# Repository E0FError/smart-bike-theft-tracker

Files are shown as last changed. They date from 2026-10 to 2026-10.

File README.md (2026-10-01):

# Smart Bike Theft Tracker — GPS + LoRaWAN, Ultra-Low Power







A complete, analysis-driven hardware design for an **anti-bike-theft tracker**:
an ultra-low-power device that sleeps until an accelerometer detects movement,
then acquires its position with GPS and transmits an alert with coordinates over
**LoRaWAN**. The design covers everything the brief demanded — a deep-sleep MCU,
a full battery/charger/regulator power tree, motion sensing, GPS, RF layout and
a quantified **power budget**.

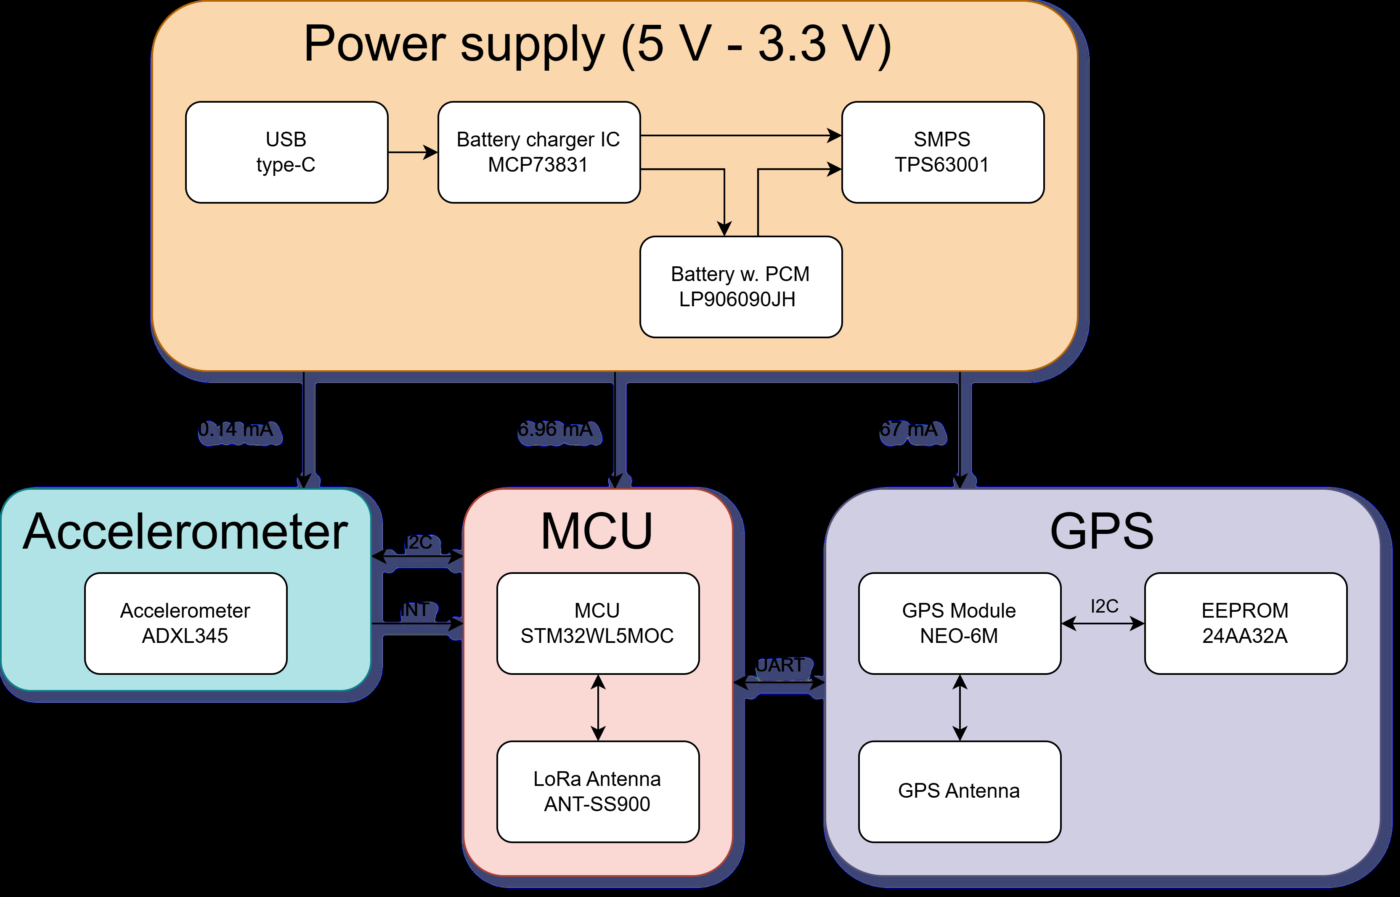
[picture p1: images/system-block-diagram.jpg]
System block diagram


> **Group 11 — co-designed.** This was the two-person final project for the DTU
> course *34374 IoT Hardware and PCB Design*, built with
> **Louis Sønderby Pelletier**. The report is included in
> [`docs/`](docs/Group11_Final_Project_Report.pdf).

---

## What I worked on

The project was a full two-person collaboration. From the report's group
contribution table, my (**Finn Oskar Grabbe**) primary ownership was:

| Area | My contribution |
|---|---|
| Accelerometer | Component choice + `GyroSense` schematic + layout |
| GPS | Component choice + `GPS` schematic + layout |
| PCB layout | Board layout (placement, routing, RF feeds) |

Louis led the introduction/architecture, the MCU and power-supply component
choices, the power design and the power budget, plus the power/MCU schematics
and layout. Everything was reviewed together.

---

## Design at a glance

| Parameter | Value |
|---|---|
| Application | Bike theft tracker: motion → GPS fix → LoRaWAN alert |
| MCU + radio | **STM32WL5MOCH6TR** (Cortex-M4 + M0+, integrated LoRaWAN, no external crystals/matching) |
| Motion sensor | **ADXL345BCCZ-RL7** 3-axis accelerometer, interrupt to MCU `WKUP1` |
| GPS | **u-blox NEO-6M-0-001** (UART NMEA) + U.FL antenna + backup cell |
| LoRa antenna | SMA edge launch (`SMA-J-P-H-ST-EM1`) for an `ANT-SS900` |
| Arming | 2-position slide switch (`500SSP1S1M2QEA`) on an MCU GPIO |
| Charger | **MCP73831T-2ACI/OT** from USB-C |
| Battery | **Jauch LP605060JU**, 1900 mAh LiPo with protection (PCM) |
| Regulator | **TPS63001** buck-boost → 3.3 V (chosen over an LDO) |
| Peak current | ≈ 74 mA (MCU 7 mA + accelerometer 0.14 mA + GPS 67 mA) |
| Battery life | **≈ 5.4 days** worst case; ≈ weekly charging in practice |
| PCB | 4-layer FR-4, ≈ 57 × 41 mm, 50 Ω controlled-impedance RF |

---

## 1. System architecture

Four functional blocks map directly onto the hierarchical schematic:

| Sheet | Block | Key parts |
|---|---|---|
| `Top.SchDoc` | Hierarchy | `U_GPS`, `U_GyroSense`, `U_MCU`, `U_BatteryCharger` |
| `BatteryCharger.SchDoc` | Power | MCP73831 charger, TPS63001 buck-boost, USB-C, JST, slide switch |
| `MCU.SchDoc` | Compute + radio | STM32WL5MOCH6TR, LoRa SMA, decoupling |
| `GyroSense.SchDoc` | Motion | ADXL345, I²C pull-up, decoupling |
| `GPS.SchDoc` | Positioning | NEO-6M, U.FL antenna, backup cell, load-switch gating |

### Operation

1. **Sleep** — ARMED, no movement. MCU standby ≈ 125 nA; GPS in power-save with
   the backup domain alive; accelerometer at a low ODR.
2. **Wake** — the ADXL345 pulls its interrupt to the MCU. The MCU checks the
   slide switch: DISARMED → back to standby, ARMED → continue.
3. **GPS fix** — the GPS rail is enabled and NMEA is read over UART. The backup
   cell makes this a **hot start**.
4. **LoRa TX** — coordinates are transmitted as a LoRaWAN alert; the system
   returns to sleep.

---

## 2. Component choices

### MCU + LoRaWAN — STM32WL5MOCH6TR
The decisive advantage is the **integrated LoRaWAN radio with in-package
matching network and oscillators** — no external RF matching, no crystals —
which shrinks the board and removes the most error-prone RF layout work. It
provides I²C/SPI/UART/ADC, interrupt wake pins and a very low standby current.
It costs more (≈ €12.43) than a €5–10 STM32, but the savings in board area,
design risk and complexity justify it, and STM's documentation is excellent.

### Motion — ADXL345BCCZ-RL7
A 3-axis, 3 × 5 mm accelerometer with built-in **activity/inactivity, tap and
free-fall** detection and a FIFO. Its interrupt output drives the MCU wake pin
(`WKUP1`/`PA0`), so the system never has to poll — this is what makes the
sub-milliamp sleep budget achievable.

### GPS — u-blox NEO-6M-0-001
A self-contained receiver with a **simple UART interface** (9600 bps NMEA),
16 × 12.2 × 2.4 mm and 2.7–3.6 V. It offloads all navigation processing from
the host. The trade-off, called out in the report, is that the NEO-6 family is
**End-of-Life** — acceptable for this design because a current u-blox module is a
drop-in pin-compatible upgrade. A **backup coin cell** (`STPS0540Z` + retainer)
enables a fast hot start at the moment of theft.

### Power — MCP73831 charger, Jauch protected LiPo, TPS63001 regulator
- **MCP73831T-2ACI/OT**: single-cell 4.2 V Li-Ion/LiPo charger with a status
  output, from a USB-C receptacle (`USB4125-GF-A-0190`) with 5.1 kΩ CC pulldowns.
- **Jauch LP605060JU**, 1900 mAh, with an integrated **protection circuit
  module** — the design's stated battery-protection assumption and a size match
  for the board.
- **TPS63001 buck-boost** for 3.3 V — see below.

Full parts list: [`docs/bom.md`](docs/bom.md) ·
[`hardware/Group11_BOM.csv`](hardware/Group11_BOM.csv).

---

## 3. Power design — why a buck-boost, not an LDO

The brief required an explicit LDO-vs-SMPS comparison. An **MCP1700 LDO** was
evaluated against the **TPS63001 buck-boost** at the 74 mA peak load:

| | MCP1700 (LDO) | TPS63001 (buck-boost) |
|---|---|---|
| Minimum input | 3.3 V·1.03 + 0.35 V = **3.749 V** | **1.8 V** |
| Loss at 74 mA | 33.2 mW | 27.1 mW (η ≈ 90 %) |
| Quiescent current | **4 µA** | 51.5 µA |
| Complexity | 2 capacitors | inductor + more passives |

The LDO has the better quiescent current and simplicity, **but its minimum input
of 3.75 V is higher than the usable voltage of a LiPo cell** (down to ~3.0 V),
so it cannot hold regulation across a full discharge. The buck-boost keeps
3.3 V from 1.8 V up, and is slightly more efficient. It was therefore selected:

$$
I_{in}=\frac{3.3\,\text{V}\times74\,\text{mA}}{0.8\times3.0\,\text{V}}=101.8\,\text{mA}
\quad\text{(well under the cell's 380 mA, 0.2 C rating)}
$$

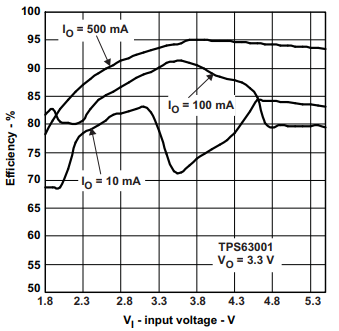
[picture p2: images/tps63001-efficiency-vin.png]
TPS63001 efficiency vs input voltage


---

## 4. Power budget & battery life

Three operating states were modelled, each component's draw taken from its
datasheet and referred to the battery through the SMPS efficiency:

| Component | Sleep | GPS fix | LoRa TX |
|---|---:|---:|---:|
| MCU | 125 nA | 1.1 mA | 1.1 mA |
| GPS | 11 mA | 47 mA | 11 mA |
| Backup battery | 879 µA | 0 mA | 0 mA |
| Accelerometer | 30 µA | 30 µA | 30 µA |
| SMPS output | 12 mA | 48 mA | 12 mA |
| **Battery discharge** | **14.7 mA** | **51.8 mA** | **14.7 mA** |

With one 1-minute hot-start fix per day:

$$
14.7\,\text{mA}\times24\,\text{h}+51.8\,\text{mA}\times\tfrac{1}{60}\,\text{h}
=353.7\ \tfrac{\text{mAh}}{\text{day}}
\;\Rightarrow\;
\text{Battery life}=\frac{1900}{353.7}=5.4\ \text{days}
$$

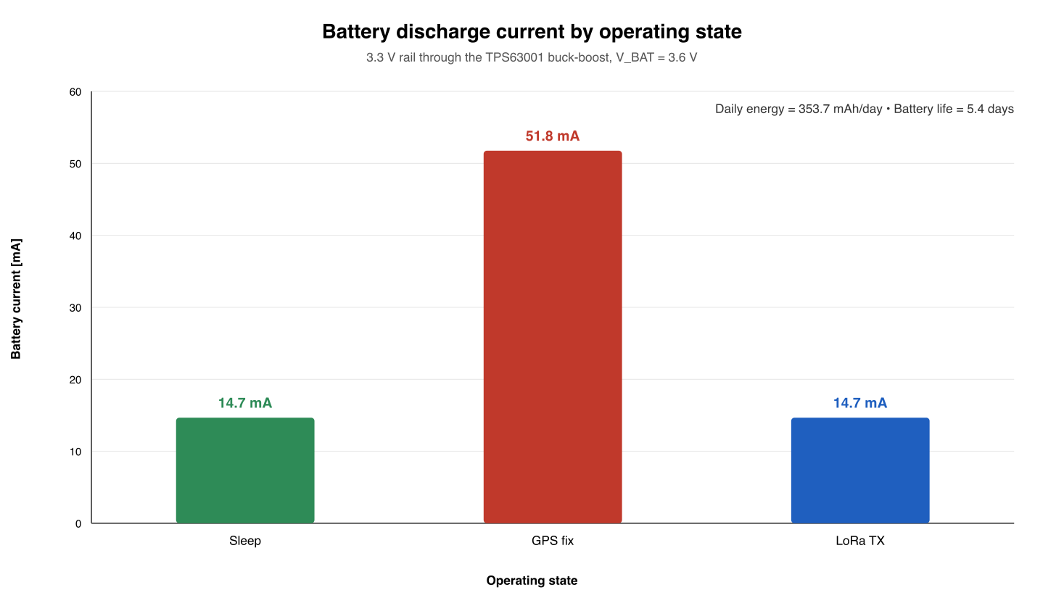
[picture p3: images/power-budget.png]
Battery discharge current by state


This 5.4 days is the **worst case** (full-use); the tracker transmits only on an
actual alert, so it needs charging roughly **once a week**.

---

## 5. RF & PCB layout

The board is a **4-layer FR-4** design (≈ 57 × 41 mm). Both antenna feeds are
**50 Ω controlled-impedance coplanar waveguides with ground**, with via stitching
to confine the field and stabilise impedance.

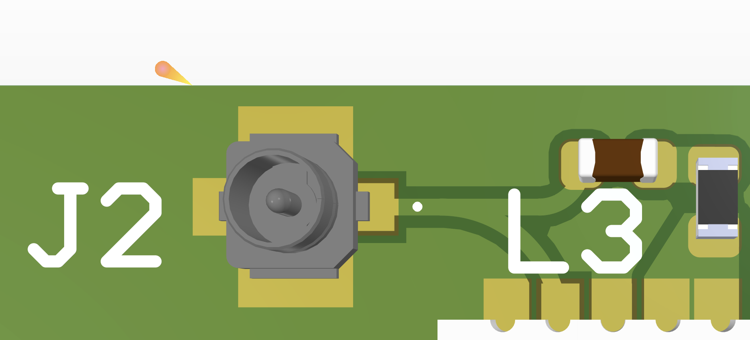
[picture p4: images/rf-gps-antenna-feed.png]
GPS antenna feed

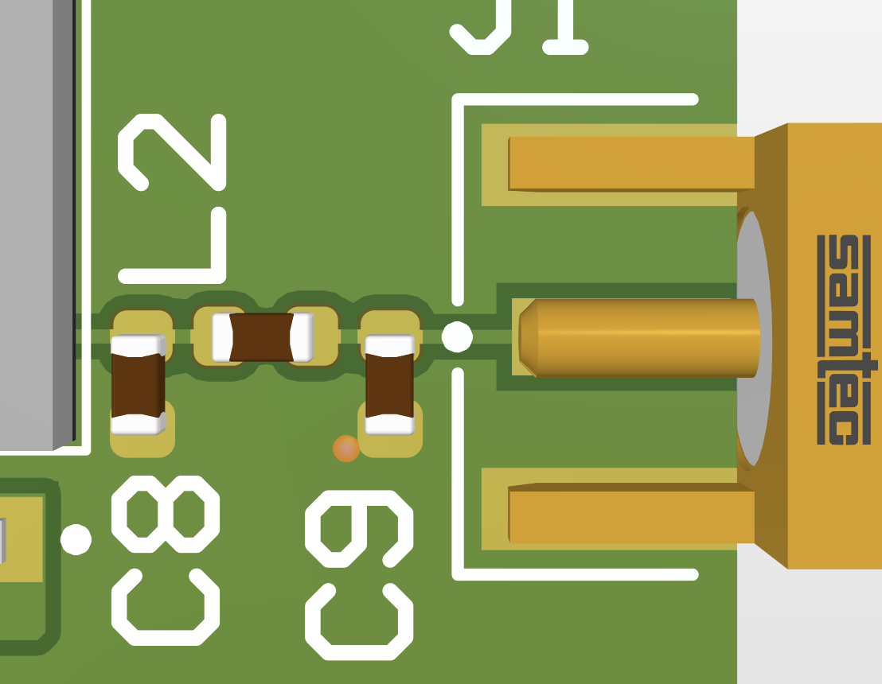
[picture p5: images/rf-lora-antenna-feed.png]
LoRa antenna feed


RF best practices applied:

- **LoRa** — straight feed to the edge-mounted SMA at 868/915 MHz.
- **GPS** — short **curved** feed to the U.FL connector at 1575.42 MHz; arcs
  avoid the impedance perturbation of 90° corners.
- **Continuous reference plane** beneath the RF traces (no splits).
- **Direct ground connections** on RF pads — thermal spokes add inductance.
- **No layer transitions** on the feeds — vias add parasitic inductance and
  reflections.

The 3.3 V rail is routed **star-style** from the regulator instead of
daisy-chaining loads, so transient currents do not create local supply dips:

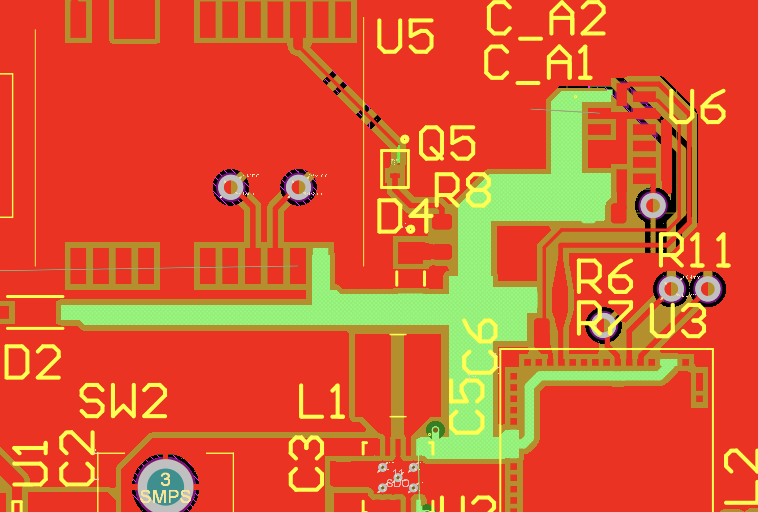
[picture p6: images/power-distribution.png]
3.3 V power distribution


---

## 6. Schematic & PCB

The design is captured as a **four-sheet hierarchical schematic** plus a
**4-layer PCB**. The full schematic PDF is in
[`hardware/Smart_Bike_Theft_Tracker_Schematics.pdf`](hardware/Smart_Bike_Theft_Tracker_Schematics.pdf).

**Top hierarchy** — the four functional blocks and the harness ports between
them:

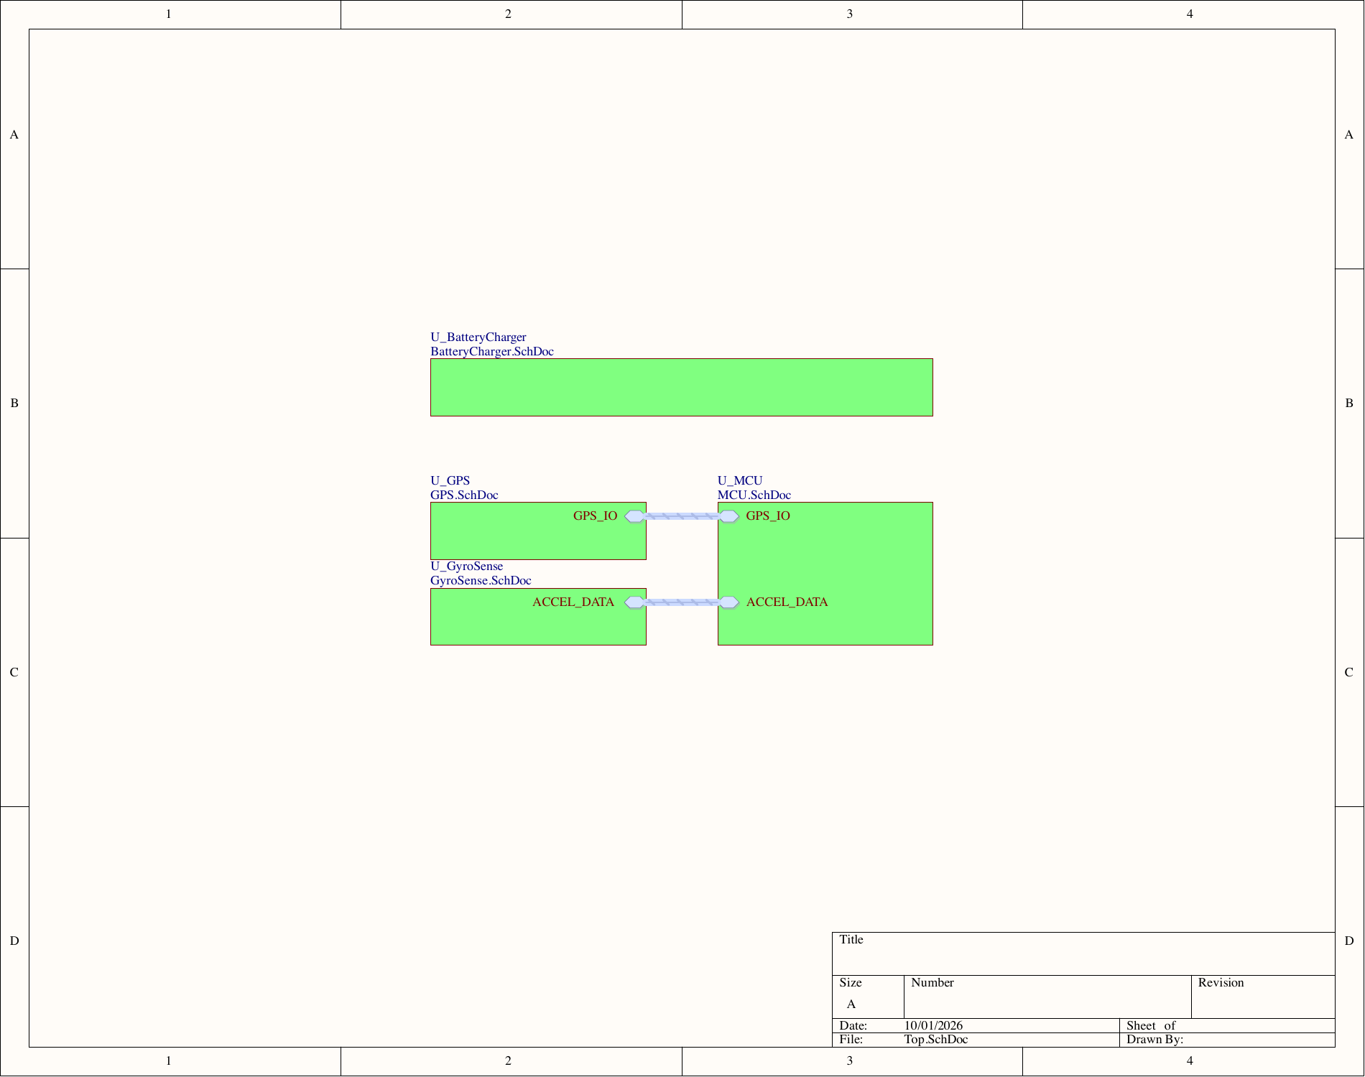
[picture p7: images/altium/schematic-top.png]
Top hierarchy sheet


| Power — charger + buck-boost | MCU + LoRaWAN |
|---|---|
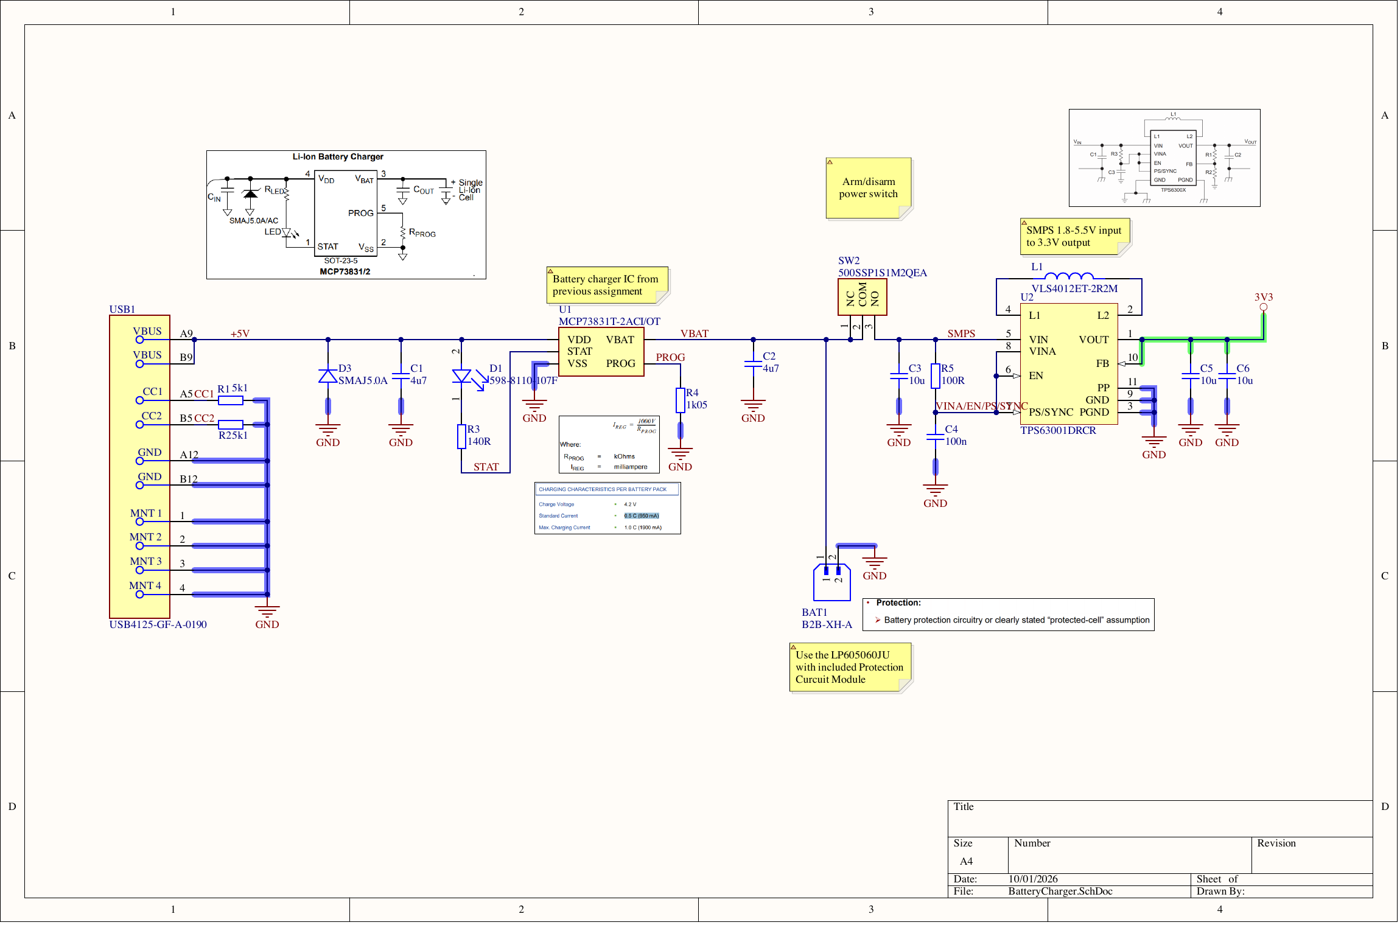
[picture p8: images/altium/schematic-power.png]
Power schematic
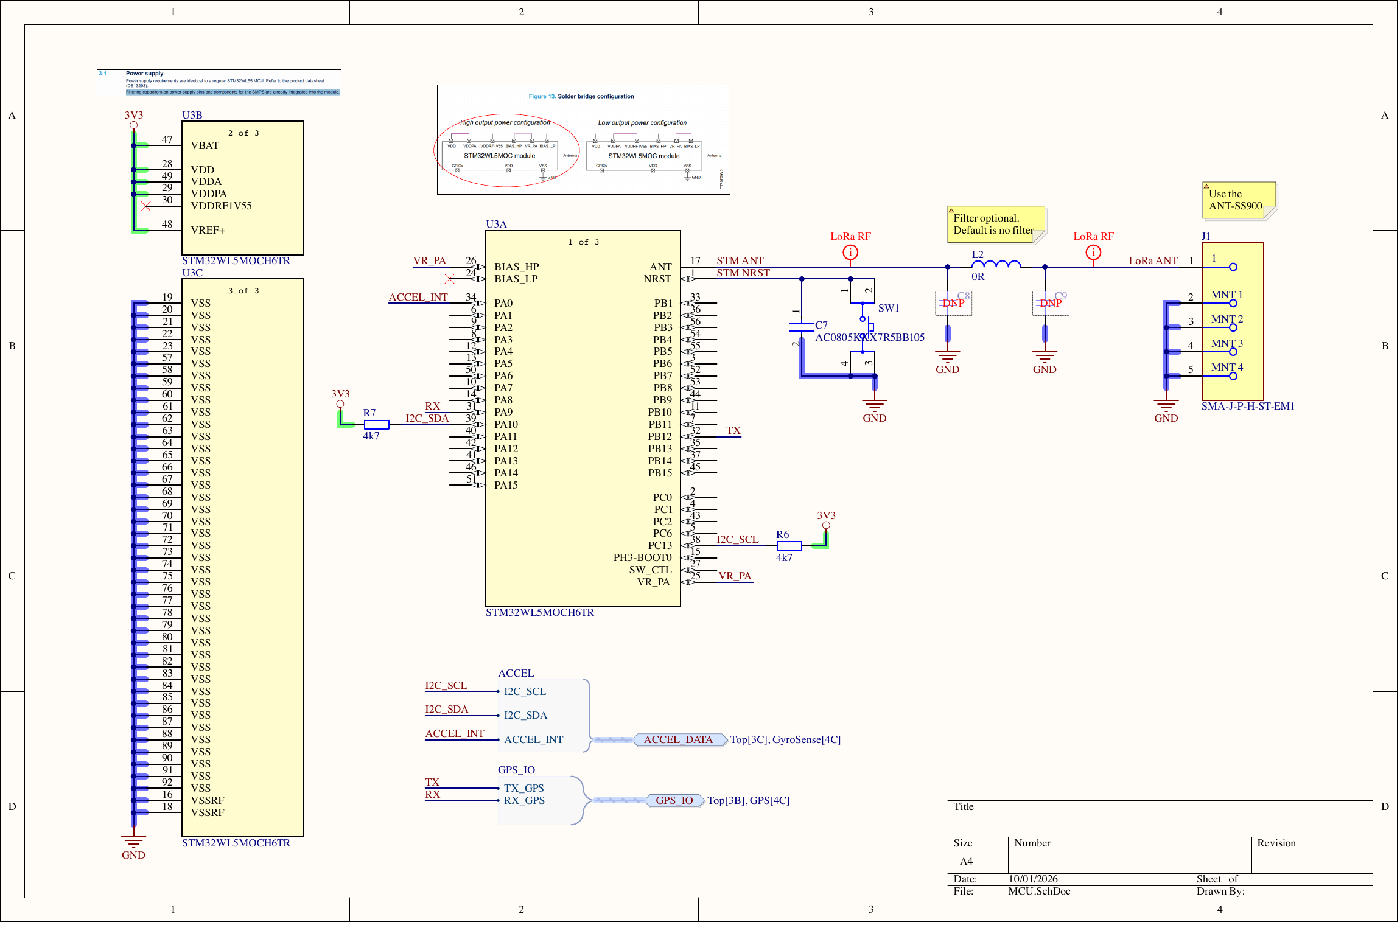
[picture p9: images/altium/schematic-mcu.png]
MCU schematic
|  |  |
| **Accelerometer (GyroSense)** | **GPS** |
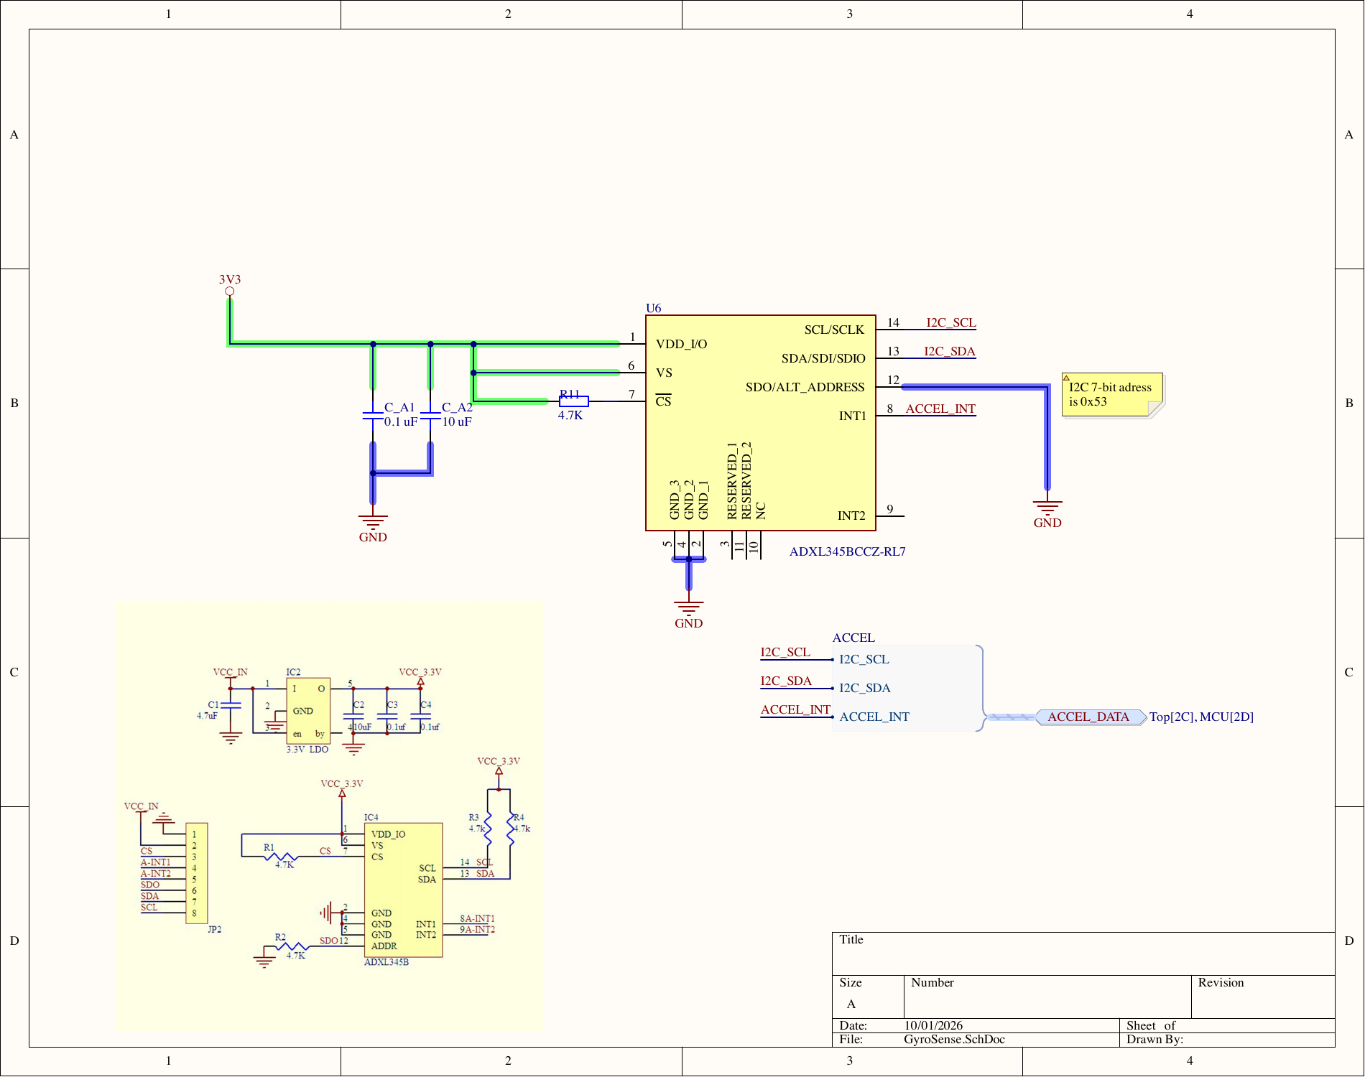
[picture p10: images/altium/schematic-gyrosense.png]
Accelerometer schematic
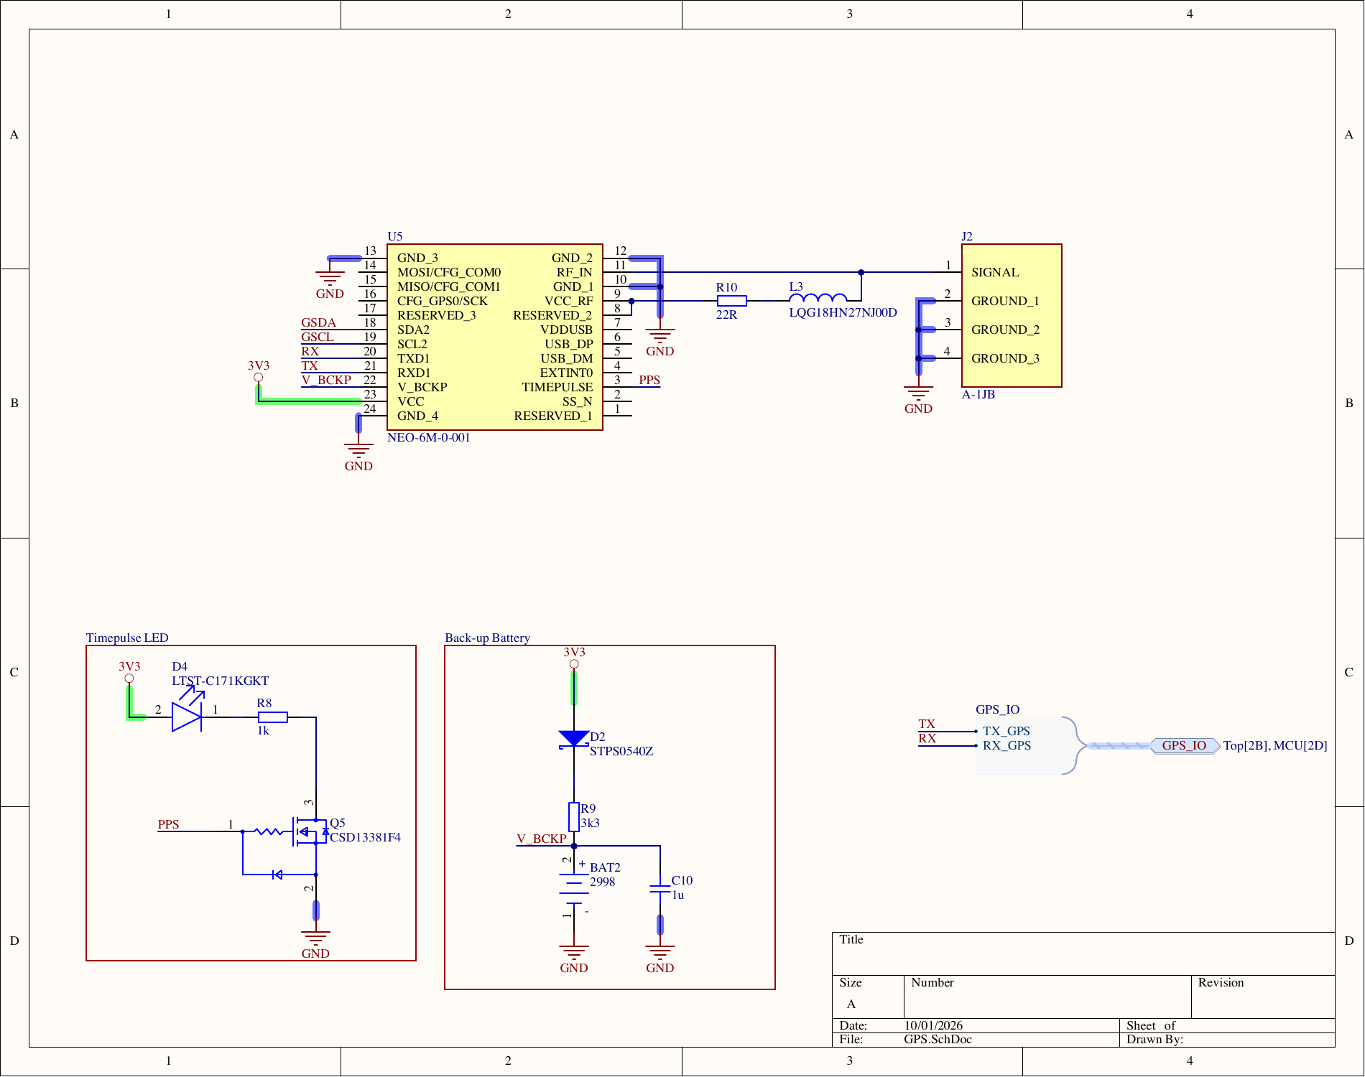
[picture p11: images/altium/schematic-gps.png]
GPS schematic
|  |  |

### PCB layout

The top-copper view shows the RF feeds, the star-distributed 3.3 V rail and the
connector placement (USB-C, JST, SMA, U.FL):

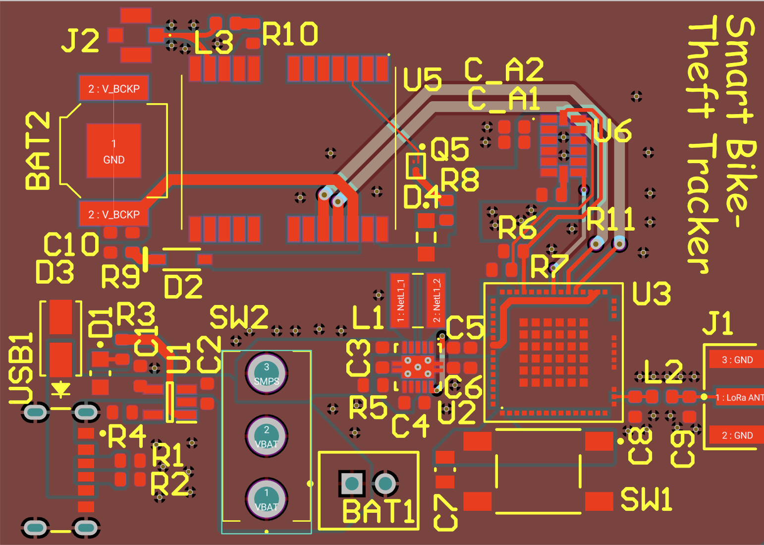
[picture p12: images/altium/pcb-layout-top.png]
PCB top layer


### 3D model

An isometric view of the assembled board. The native 3D model is included in
[`hardware/Smart_Bike_Theft_Tracker.step`](hardware/Smart_Bike_Theft_Tracker.step).

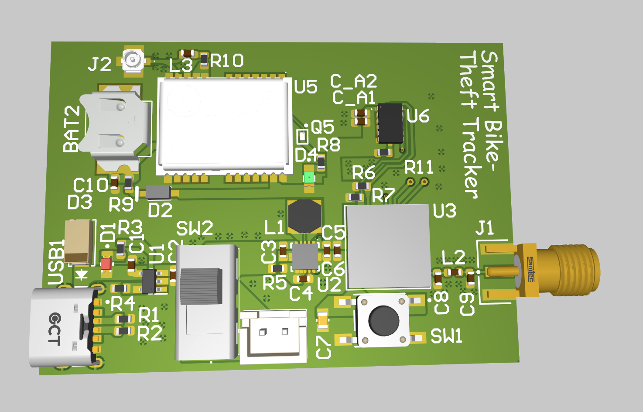
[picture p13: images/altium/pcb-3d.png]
3D render of the tracker PCB


---

## 7. Repository contents

```
smart-bike-theft-tracker/
├── README.md
├── hardware/                              # Altium project (+ generated BOM)
│   ├── Smart Bike Theft Tracker (...).PrjPcb
│   ├── Top.SchDoc  BatteryCharger.SchDoc  MCU.SchDoc
│   ├── GyroSense.SchDoc  GPS.SchDoc  *.Harness
│   ├── Smart Bike Theft Tracker.PcbDoc    # 4-layer PCB
│   ├── Schlib1.SchLib  PcbLib1.PcbLib
│   ├── Smart_Bike_Theft_Tracker_Schematics.pdf   # all sheets
│   ├── Smart_Bike_Theft_Tracker.step              # 3D model
│   └── Group11_BOM.csv
├── docs/
│   ├── Group11_Final_Project_Report.pdf   # the submitted report
│   ├── system-design.md                   # architecture + design rationale
│   └── bom.md
├── analysis/
│   ├── power_budget.py                    # states, LDO/SMPS, battery life
│   ├── extract_bom.py                     # SchDoc -> BOM CSV
│   └── power_budget.json
├── tools/
│   └── render_schdoc.py                   # Altium SchDoc -> SVG renderer
└── images/
    ├── system-block-diagram.jpg  power-budget.png
    ├── rf-gps-antenna-feed.png   rf-lora-antenna-feed.png
    ├── power-distribution.png
    └── altium/                            # exported schematic + PCB images
```

## 8. Reproducing the analysis

No third-party packages are required:

```bash
python3 analysis/power_budget.py      # power budget, LDO/SMPS, battery life + figure
python3 analysis/extract_bom.py       # regenerate hardware/Group11_BOM.csv
python3 tools/render_schdoc.py hardware/MCU.SchDoc mcu.svg --title "MCU"
```

To inspect the hardware, open the `.PrjPcb` in **Altium Designer**.

## 9. References

- STMicroelectronics — STM32WL5M dual-core LoRaWAN module.
- Analog Devices — ADXL345 3-axis digital accelerometer.
- u-blox — NEO-6M GPS receiver.
- Microchip — MCP73831 charger; Texas Instruments — TPS63001 buck-boost.
- Course material: *34374 IoT Hardware and PCB Design*, Final Project brief, DTU.

---

### Attribution & academic use

DTU 34374 final project, Group 11 — Finn Oskar Grabbe & Louis Sønderby
Pelletier. Shared publicly for portfolio purposes. If you are taking the course,
please use it for reference only and produce your own work.

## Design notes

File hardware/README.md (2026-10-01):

# Hardware sources (Altium Designer)

Altium Designer project for the **Smart Bike Theft Tracker**
(GPS + LoRaWAN, ultra-low power), Group 11.

| File | Contents |
|---|---|
| `Smart Bike Theft Tracker (GPS + LoRaWAN, Ultra-Low Power).PrjPcb` | Altium project — **open this file** |
| `Top.SchDoc` | Top-level hierarchy |
| `BatteryCharger.SchDoc` | USB-C, MCP73831 charger, TPS63001 buck-boost |
| `MCU.SchDoc` | STM32WL5MOCH6TR + LoRa antenna |
| `GyroSense.SchDoc` | ADXL345 accelerometer |
| `GPS.SchDoc` | NEO-6M GPS + antenna + power gating |
| `*.Harness` | Harness definitions for the sheet ports |
| `Smart Bike Theft Tracker.PcbDoc` | 4-layer PCB layout |
| `Schlib1.SchLib` / `PcbLib1.PcbLib` | Symbols and footprints |
| `Smart_Bike_Theft_Tracker_Schematics.pdf` | All schematic sheets, exported from Altium |
| `Smart_Bike_Theft_Tracker.step` | 3D STEP model of the assembled board |
| `Group11_BOM.csv` | BOM exported by `../analysis/extract_bom.py` |

## Opening the project

1. Open **Altium Designer**.
2. `File → Open` and select the `.PrjPcb` file above.
3. The four hierarchical sheets and the PCB load automatically.

## Notes

- The board is a **4-layer** stack; the RF feeds are 50 Ω controlled-impedance
  coplanar waveguides with ground (see the design notes).
- Altium artefacts (`__Previews/`, `History/`, `Project Logs*/`,
  `Project Outputs*/`) are excluded by `.gitignore` and regenerate on open.
- High-resolution schematic and PCB images exported from Altium live in
  [`../images/altium/`](../images/altium/).

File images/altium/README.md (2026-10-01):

# Image exports

Board images from the Altium project for the **Smart Bike Theft Tracker**
(DTU 34374 final project, Group 11).

| File | View |
|---|---|
| `schematic-top.png` | Top-level hierarchy — four sheet symbols and the harness ports between them |
| `schematic-power.png` | `BatteryCharger.SchDoc` — USB-C, MCP73831 charger, TPS63001 buck-boost |
| `schematic-mcu.png` | `MCU.SchDoc` — STM32WL5MOCH6TR and the LoRa SMA feed |
| `schematic-gyrosense.png` | `GyroSense.SchDoc` — ADXL345 accelerometer |
| `schematic-gps.png` | `GPS.SchDoc` — NEO-6M, U.FL antenna and backup cell |
| `pcb-layout-top.png` | PCB top-copper layer — RF feeds, 3.3 V rail and connector placement |
| `pcb-3d.png` | Isometric 3D view of the assembled board |

The native design files — schematics, PCB, symbol/footprint libraries, the
schematic PDF and the STEP 3D model — are in
[`../../hardware/`](../../hardware/).

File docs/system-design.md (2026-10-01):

# System design — Smart Bike Theft Tracker

Design rationale for the GPS + LoRaWAN ultra-low-power bike theft tracker.
Numbers match the design report and the scripts in `analysis/`.

---

## 1. Requirements

| # | Requirement | Implementation |
|---|---|---|
| 1 | Motion detection that can wake the MCU from deep sleep | **ADXL345** activity interrupt → MCU `WKUP1`/`PA0` |
| 2 | ARMED / DISARMED user control | 2-position **slide switch** on an MCU GPIO |
| 3 | Acquire position | **u-blox NEO-6M** GPS over UART + antenna |
| 4 | Transmit alert + coordinates | **STM32WL5M** integrated LoRaWAN + SMA antenna |
| 5 | Battery-powered with charger and regulation | USB-C → **MCP73831** → 1900 mAh LiPo → **TPS63001** 3.3 V |
| 6 | 50 Ω controlled-impedance RF feeds and antenna placement | Coplanar waveguide with ground on a 4-layer stack |

The brief is **design & analysis only** — no fabrication, purchasing or assembly.

---

## 2. System architecture

System block diagram

The device is organised into four functional blocks that mirror the schematic
hierarchy:

| Sheet | Block | Key parts |
|---|---|---|
| `Top.SchDoc` | Hierarchy | sheet symbols `U_GPS`, `U_GyroSense`, `U_MCU`, `U_BatteryCharger` |
| `BatteryCharger.SchDoc` | Power | MCP73831 charger, TPS63001 buck-boost, USB-C, JST, slide switch |
| `MCU.SchDoc` | Compute + radio | STM32WL5MOCH6TR, LoRa SMA connector, decoupling |
| `GyroSense.SchDoc` | Motion | ADXL345, I²C pull-up, decoupling |
| `GPS.SchDoc` | Positioning | NEO-6M, U.FL antenna, backup cell, power gating |

Data flows: the accelerometer raises an interrupt, the MCU reads it over I²C,
checks the slide-switch state, powers up the GPS, reads NMEA over UART and then
transmits the fix over the integrated LoRaWAN radio.

### Firmware / operation flow

1. **SLEEP** — ARMED, no movement. MCU in standby (`125 nA`), GPS in power-save
   with its backup domain alive, accelerometer at a low ODR only for interrupts.
2. **Motion interrupt** — the ADXL345 pulls the wake pin; the MCU wakes and
   checks the slide switch. If DISARMED it ignores the event and returns to
   standby.
3. **GPS FIX** — the MCU enables the GPS rail (via the load MOSFET) and reads
   NMEA over UART. A hot start is assumed because the backup cell keeps the
   ephemeris.
4. **LoRa TX** — the coordinates are sent as a LoRaWAN alert; the system then
   returns to sleep.

---

## 3. Component choices

### MCU + LoRaWAN — STM32WL5MOCH6TR
- Dual-core Cortex-M4 (application) + Cortex-M0+ (radio), with the **SX126x
  LoRa radio integrated in-package**.
- Integrated oscillator network and antenna matching/PA network — **no external
  crystals or discrete matching** required, which shrinks the PCB and removes RF
  layout risk.
- I²C, SPI, UART, ADC and interrupt-capable wake pins, with a very low standby
  current. The trade-off is cost (≈ €12.43 vs €5–10 for similar STM32s), which is
  outweighed by reduced complexity, size and STM's documentation/support.

### Accelerometer — ADXL345BCCZ-RL7
- 3-axis, I²C/SPI, 3 mm × 5 mm package, FIFO and built-in **activity / tap /
  inactivity / free-fall** detection.
- Its interrupt output connects to `WKUP1` (`PA0`) so the sensor can wake the
  system directly from deep sleep — no polling, which is what makes the
  low-power budget possible.

### GPS — u-blox NEO-6M-0-001
- Self-contained receiver with a **simple UART** interface (default 9600 bps
  NMEA), 16 mm × 12.2 mm × 2.4 mm, 2.7–3.6 V.
- Drawback: the NEO-6 family is **End-of-Life**; acceptable here because the
  module removes navigation processing from the host and is easy to power-gate.
- A **backup coin cell** (retainer + Schottky `STPS0540Z`) keeps the RTC and
  ephemeris alive so the theft fix can be a **hot start**.

### Charger — MCP73831T-2ACI/OT + Jauch LP605060JU
- 4.2 V single-cell Li-Ion/LiPo charger, programmable current, status output.
- Battery: **Jauch LP605060JU, 1900 mAh**, with an integrated **protection
  circuit module (PCM)** — this is the stated battery-protection assumption.
- USB-C input (`USB4125-GF-A-0190`) with 5.1 kΩ CC pull-downs.

### Regulator — TPS63001 (chosen over an LDO)
See §4.

---

## 4. Power design: LDO vs buck-boost

An **MCP1700 LDO** was compared against the **TPS63001 buck-boost** for the
3.3 V rail at the 74 mA peak load.

| Criterion | MCP1700 (LDO) | TPS63001 (buck-boost) |
|---|---|---|
| Minimum input | 3.3 V·1.03 + 0.35 V = **3.749 V** | **1.8 V** |
| Loss at peak load | 33.2 mW | 27.1 mW (η ≈ 90 %) |
| Quiescent current | **4 µA** | 51.5 µA |
| Complexity | 2 capacitors | inductor + more passives |

The LDO wins on quiescent current and simplicity, but its **minimum input of
3.75 V is above the usable voltage of a LiPo cell** (which falls to ~3.0 V). It
therefore cannot regulate across the whole discharge curve, while the
buck-boost both keeps 3.3 V down to 1.8 V in and is slightly more efficient.
The **TPS63001** was selected on that basis:

$$
P_{out}=3.3\,\text{V}\times74\,\text{mA}=244.2\,\text{mW},\qquad
I_{in}=\frac{244.2\,\text{mW}}{0.8\times3.0\,\text{V}}=101.8\,\text{mA}
$$

which is well within the cell's 0.2 C (≈380 mA) discharge rating.

TPS63001 efficiency vs input voltage

---

## 5. Power budget & battery life

Three states are defined; each component's current draw comes from its
datasheet, and the SMPS efficiency converts the 3.3 V load into battery current:

$$
I_{bat}=\frac{V_{rail}\cdot I_{out}}{\eta\cdot V_{bat}}
$$

| Component | Sleep | GPS fix | LoRa TX |
|---|---:|---:|---:|
| MCU | 125 nA | 1.1 mA | 1.1 mA |
| GPS | 11 mA | 47 mA | 11 mA |
| Backup battery | 879 µA | 0 mA | 0 mA |
| Accelerometer | 30 µA | 30 µA | 30 µA |
| **SMPS output** | 12 mA | 48 mA | 12 mA |
| **Battery discharge** | **14.7 mA** | **51.8 mA** | **14.7 mA** |

Daily energy (one 1-minute hot-start fix per day):

$$
14.7\,\text{mA}\times24\,\text{h}+51.8\,\text{mA}\times\tfrac{1}{60}\,\text{h}
=353.7\ \tfrac{\text{mAh}}{\text{day}}
$$

$$
\text{Battery life}=\frac{1900\,\text{mAh}}{353.7\,\text{mAh/day}}
=5.4\ \text{days (worst case)}
$$

Battery discharge current by state

In practice the GPS only needs a fix at an alert, so the tracker only needs
charging about **once a week**.

---

## 6. RF & PCB layout

The board is a **4-layer FR-4** stack. Both antenna feeds are **50 Ω
controlled-impedance coplanar waveguides with ground**, with **via stitching**
to confine the field and stabilise the impedance.

GPS antenna feed
LoRa antenna feed

RF rules applied:

- **LoRa:** straight feed to the edge-mounted SMA (`SMA-J-P-H-ST-EM1`) for the
  `ANT-SS900` antenna, at 868/915 MHz.
- **GPS:** short, **curved** trace to the `A-1JB` U.FL connector at 1575.42 MHz;
  arcs are preferred over 90° corners to avoid impedance perturbations.
- **Continuous reference plane** under every RF trace — no splits, since a
  discontinuity in the return path degrades the effective impedance.
- **Direct ground connections** (no thermal spokes) on RF ground pads, because
  spokes add inductance at RF.
- **No layer transitions** on the feeds — vias would add parasitic inductance
  and reflections.

### Power distribution

The 3.3 V rail is distributed **star-style** directly from the buck-boost
rather than daisy-chained, so transient current from one block does not create
a supply dip at another:

3.3 V power distribution

---

## 7. Assumptions & limitations

- Analysis only: no board was fabricated, so all currents/efficiency figures
  are datasheet- or simulation-based.
- GPS fix time assumed to be **1 minute** (datasheet hot start ≈ 15 s) as a
  conservative margin.
- SMPS efficiencies assumed 75 % (light load) / 85–90 % (heavy load) from the
  datasheet curves.
- The `NEO-6M` is End-of-Life; a production revision would move to a current
  u-blox module.
- Battery protection is credited to the cell's integrated PCM.
- The slide switch is a proof of concept for ARM/DISARM; the report notes NFC
  as a more realistic product-grade alternative.

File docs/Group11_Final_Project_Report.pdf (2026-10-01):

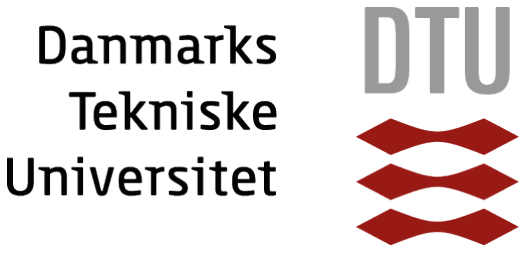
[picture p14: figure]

# Smart Bike Theft Tracker

Authors

Finn Oskar Grabbe - s252818 Louis Sønderby Pelletier - s254381

May 29, 2026

Smart Bike Theft Tracker | Contents

# Contents

1 Introduction & Requirements | 2
2 System Architecture | 3
3 Component Choices | 4
4 Power Design | 6
5 RF & PCB Layout | 8
6 Power Budget & Battery Life | 10
Chapter/HW block | Author
Intro | Louis
Architecture | Louis
Comp. MCU | Louis
Comp. AMU | Finn
Comp. GPS | Finn
Comp. Power supply | Louis
Power design | Louis
PCB Layout | Finn
Power budget | Louis
Power supply schem. & layout | Louis
MCU schem. & layout | Louis
AMU schem. & layout | Finn
GPS schem. & layout | Finn

Smart Bike Theft Tracker

# 1 Introduction & Requirements

The goal of this project is to design the hardware aspect of an anti bike theft device, that has the capability to detect motion, pinpoint bike location using GPS and transmitting an alert and bike coordinates via LoRa to the bike owner in case of theft. The device must also include a way to arm and disarm the device (e.g. a switch) to avoid false theft detection, and the device must also include an ultra low power mode to limit current draw while it is stationary or in the unarmed state.
We will implement motion detection using an accelerometer, that has the capability of producing an interrupt when movement is detected. This will be used to wake the MCU up from the deep sleep state in case the bike is armed and is stolen.
To arm and disarm the device, we will use a slide switch as a proof of concept. In practice a slide switch is too simple and obvious for a device of this nature, but implementing a different arming solution is not complicated (NFC would be a good alternative for a device like this). While the device is armed, the interrupt from the accelerometer will tell the MCU that the device is being stolen, and while the device is unarmed the MCU will stay in sleep mode.
A GPS will track the position of the device, and in case of a theft the MCU will get the current coordinates from here. The GPS will require an antenna to establish a connection to satellites. In case of a theft, the owner of the bike will receive an alert on their mobile device through LoRa along with the current coordinates of the bike.

Smart Bike Theft Tracker

# 2 System Architecture

A block diagram of the Smart Bike Theft tracker can be seen in figure 2.1. It shows each major block of the system with key components under each block. The peak current draw of key blocks is also included to provide an overview of total current draw and the balance of power draw of each major block.
The power supply block is powered through a USB type-C terminal to comply with EU legislation. A battery charger IC uses the 5 V from the USB to charge the battery and to drive the Switch Mode Power Supply, which powers the rest of the system with 3.3 V.
The accelerometer draws 140 µA of current at peak and will send an interrupt to the MCU block when movement is detected. The MCU can communicate with the accelerometer through I2C. The MCU draws about 7 mA at peak current draw. This includes the draw of the LoRa module as it is included in the MCU chip.
The GPS block will have the largest current draw at peak, but the 67 mA is a worst case scenario over several GPS modules in NEO-6 family. It will likely be lower in practice. In total the peak current draw will be about 74 mA.

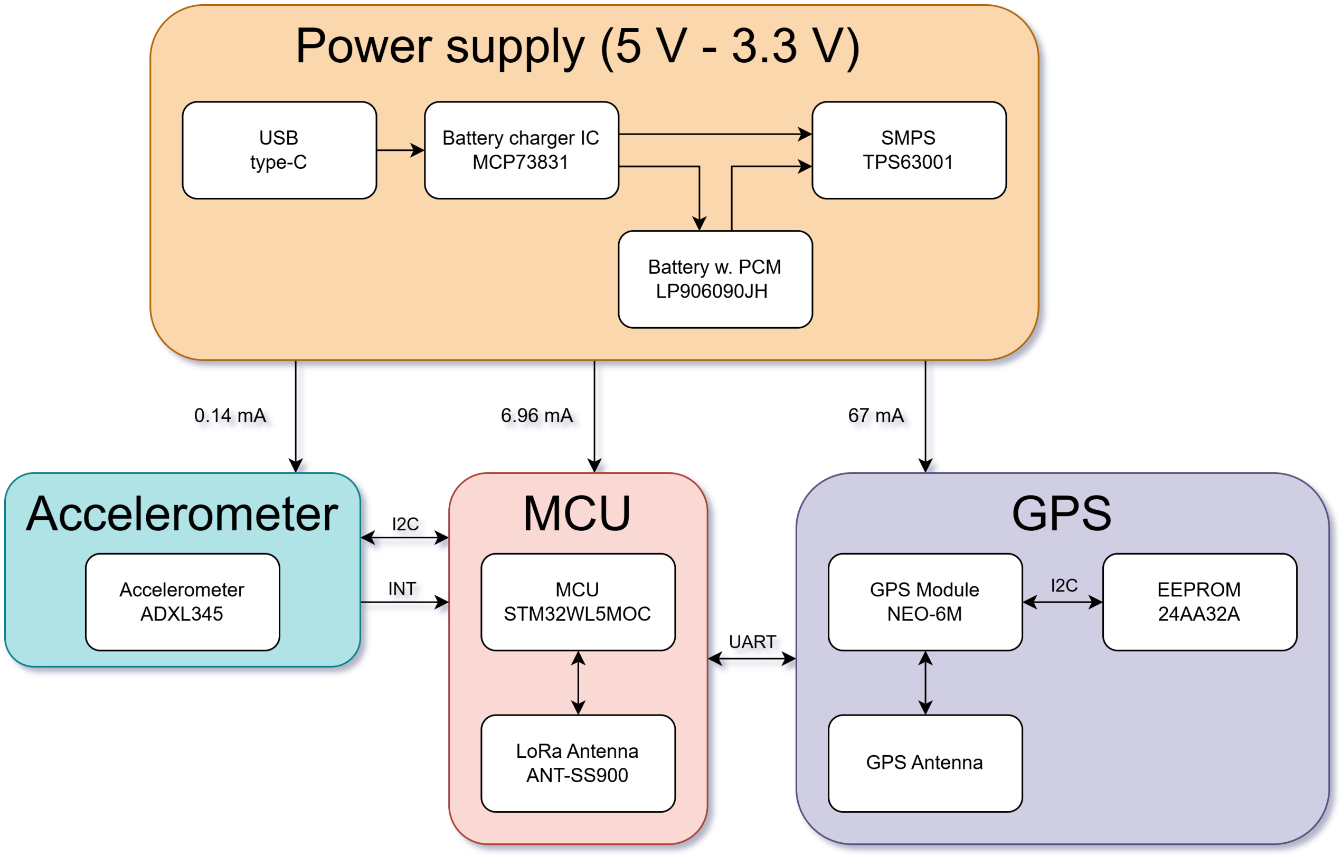
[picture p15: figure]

Figure 2.1: Block diagram of the Bike theft device

Smart Bike Theft Tracker

# 3 Component Choices

This chapter explains the choices that were made for each of the components used in the Smart Bike Theft Tracker design.

## 3.1 MCU & LoRaWAN

For the MCU we have chosen the STM32WL5MOCH6TR from STMicroelectronics, which has an integrated LoRaWAN module. This choice of MCU has a significant downside of costing 12.43 EUR, which is more expensive than other popular microcontrollers from STM that are in the price range of 5-10 EUR, but this downside is outweighed by many upsides.
The biggest upside comes from the integrated LoRaWAN module, which decreases design complexity and size of the PCB layout. The STM32WL5MOCH6TR is equipped with internal oscillator networks eliminating the need for external crystals. The matching network for the LoRaWAN antenna along with an RF filter is not necessary in the design as it is also included in the MCU package. Because of this, the smaller PCB will result in a smaller product all together and make the Smart Bike Theft Tracker easier to hide on a bicycle, making the product more effective.
The STM32WL5MOCH6TR covers all requirements from our design conditions. That being I2C, SPI and UART communication support, interrupt pins that can wake the MCU from sleep mode, and a sleep mode with very low current draw. The second upside comes with the manufacturer, as STM has very good documentation of their products, and where other cheaper manufacturers might omit information in datasheets, STM is more likely to have it in theirs. STM also has very good support as many people use their products, and because of the open nature of the documentation, users are able to help each other with troubleshooting.
The upsides to the STM32WL5MOCH6TR, more than makes up for the larger cost.

## 3.2 Accelerometer

The ADXL345BCCZ-RL7 is a good choice for the Smart Bike Theft Tracker, even though it is more expensive than many basic accelerometers.
Its main advantage is that it can be connected to the MCU’s WKUP1 pin (PA0), so the sensor can wake the system directly from low-power sleep. Combined with its small 3 mm × 5 mm package, I2C/SPI support, FIFO buffer, and built-in motion features such as tap, activity, inactivity, and free-fall detection, it reduces PCB size, firmware complexity, and power consumption.
The higher unit cost is therefore justified by the design simplification it provides. Instead of continuously polling raw acceleration data, the tracker can rely on the ADXL345 to detect

Smart Bike Theft Tracker | 3.3. GPS

events locally and only wake the MCU when needed, which makes the final product more compact and more battery efficient.

## 3.3 GPS

The NEO-6M-0-001 GPS module is a practical choice for the Smart Bike Theft Tracker, though its main drawback is that the NEO-6 family has reached End-of-Life, making it less ideal for long-term new designs. Despite this, it remains attractive because it is a selfcontained GPS receiver with a simple UART interface that can be connected directly to the MCU without additional protocol conversion hardware. The module communicates over UART using TXD and RXD pins, with a default baud rate of 9600 bps that is sufficient for standard NMEA output and keeps the interface straightforward to implement and debug. Physically, the module measures approximately 16 mm × 12.2 mm × 2.4 mm, which keeps the PCB compact and leaves room for the battery and radio section. It operates from 2.7 V to 3.6 V, and many breakout versions accept 3 V to 5 V input, simplifying integration with common MCU boards. For this project, the NEO-6M-0-001 reduces design complexity by providing ready-to-use position data over serial, eliminating the need for the host processor to handle navigation signal processing, which simplifies firmware and shortens development time. In a theft tracker, this is valuable because the GPS subsystem should remain small, reliable, and easy to power-manage by waking only when needed.

## 3.4 Battery charger IC

We have chosen the MCP73831-2ACI/OT battery charger IC from Microchip and the LP605060JU lithium polymer battery from Jauch Quartz as the charging and battery solution. The charger IC is designed for both lithium ion and lithium polymer battery chargers and the battery charge voltage is also compatible with the charger IC at 4.2 V. The battery has a built in protection circuit module, keeping it from discharging the voltage too low or charging it too high and for preventing high currents in the battery.
The battery was chosen for its size, as it closely matches the dimensions of the PCB. This will minimize the final size of the theft tracker, making it easier to hide. The battery has a capacity of 1900 mAh.
We have chosen the TPS63001 as the switch mode power supply as it will be effective in converting the battery voltage to the correct 3.3 V rail needed for the MCU and peripherals. Calculations for the power supply solution will be carried out in the next chapter.

Smart Bike Theft Tracker

# 4 Power Design

We will choose between an LDO and an SMPS to drive the 3.3 V power rail of out design. We will do this based on the efficiency, the quiescent current and the complexity tied to the solution. We will start by looking at an LDO for which we have gone with the MCP1700, which is a popular LDO that is capable of regulating voltages from 1.2-5 V. The input of the LDO must be at least (3.3 V + 3%) + VDROP OUT . The dropout voltage of the MCP1700 is 350 mV max. This gives a minimum input of 3.749 V, which is already larger than the nominal voltage of a LiPo battery cell. Assuming the battery can hold the minimal voltage necessary for operation, and the max current is drawn from the LDO, the power loss can be calculated.

Ploss = (3.749 V − 3.3 V) · 74 mA = 33.226 mW | (4.1)

The MCP1700 has a max quiescent current of 4 µA at no load. Despite the downsides it has very low complexity, as only two capacitors are needed apart from the LDO itself. Looking at the chosen TPS63001 SMPS we see the minimum input is 1.8, well below the minimal battery voltage of 3 V. The efficiency of the SMPS can be seen in figure 4.1. We see at an output current of 100 mA, the efficiency is around 90% at the voltage range of the LiPo battery. This corresponds to a loss of 27.133 mW. The quiescent currrent when no load is applied to the SMPS is up to 51.5 µA. This is a lot more than the LDO. Finally, the complexity of the TPS63001 is more intricate, as more components and different types, like an inductor, are necessary.


Figure 4.1: Efficiency of the TPS63001 SMPS versus the input voltage.

Smart Bike Theft Tracker

To conclude the comparison, the LDO beats the SMPS in quiescent current and complexity, but the SMPS beats the LDO with a small margin in efficiency, however the LDO will not operate optimally once the battery dips below the minimum LDO input voltage. Because of this we have chosen the TPS63001 SMPS as the driver of the 3.3 V rail.

As stated in an earlier chapter, the peak current draw of the MCU, accelerometer and GPS is about 74 mA, which is satisfied by the SMPS as it has a max current output of at least 1.2 A at the battery voltage of around 3.0-3.7 V input. See figure 4.2.

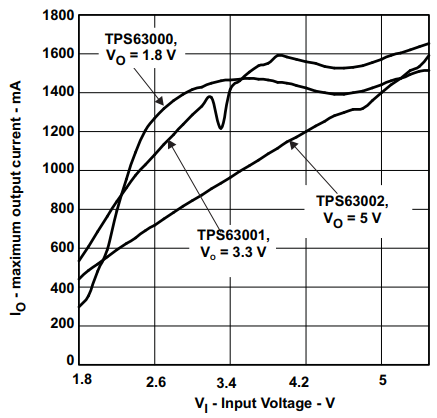
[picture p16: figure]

Figure 4.2: Output current of the TPS63001 SMPS versus the input voltage.

The output power from the SMPS is 3.3 V · 74 mA = 244.2 mW. If we assume the efficiency of the SMPS to be 80% in the worst case scenario and the input voltage at the minimal battery voltage, the input current will be 244.2 mW/(0.8 · 3 V ) = 101.75 mA. This discharge current is satisfied by the battery as the standard discharge current at 0.2 C is 380 mA.

Smart Bike Theft Tracker

# 5 RF & PCB Layout

## 5.1 RF Antenna Routing

The RF routing for both the LoRa and GPS antennas has been implemented according to standard high-frequency design practice on a 4-layer FR-4 PCB. The LoRa feed is routed in a straight line to the SMA-J-P-H-ST-EM1 connector, while the GPS feed is kept short and curved toward the A-1JB antenna. Both paths are designed as 50 Ω controlled-impedance transmission lines in order to minimize return loss and maintain proper signal integrity at the operating frequencies of 868/915 MHz for LoRa and 1575.42 MHz for GPS. The resulting GPS feed geometry is illustrated in Figure 5.1a, while the overall LoRa antenna feed is shown in Figure 5.1b.
The use of a coplanar waveguide with ground shielding and via stitching is technically appropriate for these RF paths. This structure helps confine the electromagnetic field, improves impedance stability, and reduces susceptibility to external noise and coupling from nearby traces. The ground plane beneath the RF trace must remain continuous and free of splits or interruptions, since any discontinuity in the reference plane can distort the return current path and degrade the effective impedance.
For the RF ground pads, direct connection to the ground pour is preferred over thermal relief connections. Thermal spokes introduce unnecessary inductance into the ground return path, which is undesirable at RF frequencies, particularly at the GPS frequency where even small parasitics can impact matching. Direct connections provide a lower-impedance grounding structure and are therefore better suited for antenna feed regions and other sensitive high-frequency circuitry.
Layer transitions through vias are avoided wherever possible on both the LoRa and GPS feeds. Vias introduce parasitic inductance and create small impedance discontinuities that can reduce matching quality and increase reflections. For this reason, the RF traces in Figures 5.1a and 5.1b are kept on the top layer for the entire antenna feed path.
The curved GPS routing is also preferred over sharp 90-degree corners. While 45-degree mitred bends are acceptable in RF design, curved arcs provide a smoother geometry and reduce local impedance perturbations even further. At 1575.42 MHz, the electrical effect of a bend is usually small if the trace is short and well-controlled, but rounded routing as implemented in Figure 5.1a remains the cleaner solution from a signal-integrity perspective. Overall, the selected routing strategy follows established RF design principles by preserving a controlled 50 Ω impedance, limiting discontinuities, reducing EMI, and maintaining a compact layout. This is particularly important for a battery-powered tracking device, where reliable antenna performance and low-loss RF routing directly affect system range and overall effectiveness.

Smart Bike Theft Tracker | 5.1. RF Antenna Routing

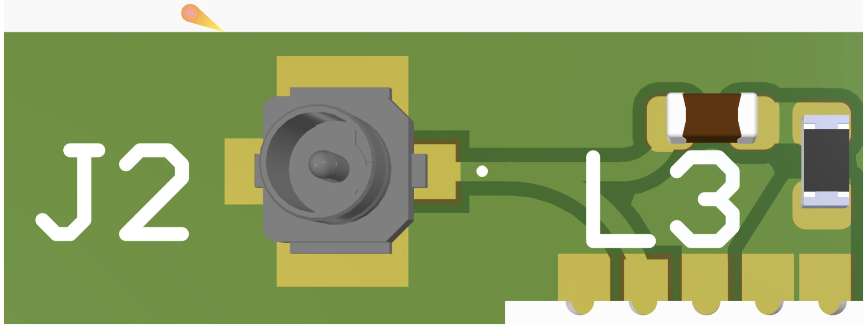
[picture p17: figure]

(a) GPS antenna feed routing showing the short, curved 50 Ω transmission line from the module output to the A-1JB antenna pad.


(b) LoRa antenna feed routing with a straight 50 Ω controlled-impedance path to the SMA-J-P-H-ST-EM1 connector.

Figure 5.1: RF antenna feed implementations for GPS (left) and LoRa (right).

Power Distribution The 3.3 V rail is routed as a major power backbone directly from the power-management IC, rather than daisy-chained from load to load. This star-like distribution topology reduces resistive voltage drops and minimizes the risk of local supply dips when multiple circuits draw transient current simultaneously. Sensitive RF and analog blocks are therefore fed from a low-impedance common node instead of being placed at the end of a long queue of series segments, which improves overall supply integrity as illustrated in Figure 5.2.


Figure 5.2: Conceptual 3.3 V rail distribution where all major loads are fed directly from the power IC rather than in a daisy-chain.

Smart Bike Theft Tracker

# 6 Power Budget & Battery Life

This chapter looks at the power budget of the bike tracker. We will compile the current draw of all relevant components in the design, into a table to find the current draw in the span of a day, and subsequently, the battery life. To do this we will define three power states for the bike tracker.

- Sleep mode The bike has been parked and the device is armed, but has not detected any movement. All components will be in sleep mode.
- GPS fix The device has detected a theft, is waking the MCU and attempting to get a GPS fix. A hot start is assumed.
- LoRa TX The device now has a GPS fix and will transmit coordinates over LoRa.

In the sleep mode the MCU will be in standby mode, which is the lowest sleep mode available while still being able to be woken by hardware interrupts. The RTC and register retention of the MCU will be disabled as they are not needed.
For the GPS we will use ICC tracking metric in power save mode. The backup battery discharges when the device is off and charges when it is on. We assume the battery is charging in the sleep mode and is fully charged in the other modes.
To save power, the accelerometer will operate at low output data rate, as none of the data will be read, only the interrupt is used. The SMPS outputs about 12 mA in this mode, which corresponds to an efficiency of around 75% at 3.6 V. See figure 6.1.

ISLEEP =

3.3 V · 12 mA
0.75 · 3.6 V
= 14.7 mA | (6.1)

Waking the MCU from standby mode with a wake up clock of 8 MHz uses 19.6 nAs (5.44 pAh), which is very low, so it will be excluded from the calculations. The MCU will run at 8 MHz in run mode.
The GPS will perform a hot start as it has the backup battery. This is estimated to take about 15 seconds in the datasheet, but we will assume 1 minute. The SMPS outputs 48 mA in GPS Fix mode, which is about 85% in efficiency.
We assume the bike is recovered 10 hours after being reported stolen by the device. This time span is likely to vary a lot in practice. All currents can be seen in table 6.1.

IGP S F IX =

3.3 V · 48 mA
0.75 · 3.6 V
= 51.8 mA | (6.2)

Smart Bike Theft Tracker

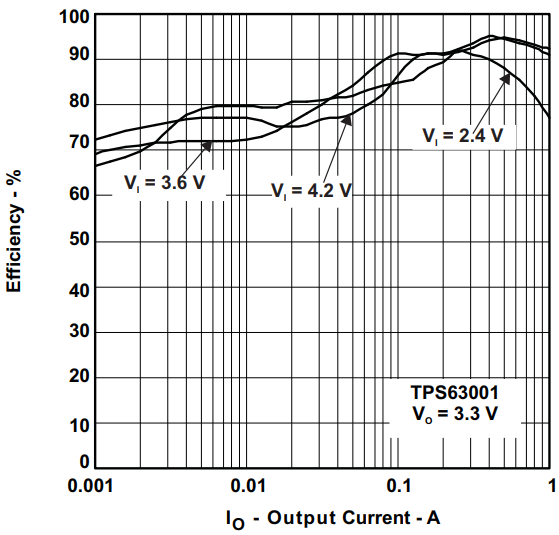
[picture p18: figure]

Figure 6.1: Efficiency of the SMPS versus the output current.

Sleep mode GPS Fix LoRa TX

MCU | 125 nA | 1.1 mA | 1.1 mA
GPS | 11 mA | 47 mA | 11 mA
Backup Battery | 879 µA | 0 mA | 0 mA
Accelerometer | 30 µA | 30 µA | 30 µA
SMPS output | 12 mA | 48 mA | 12 mA
Battery discharge | 14.7 mA | 51.8 mA | 14.7 mA
Time spent in mode | 14 h/day | 1 m/day | 10 h/day

Table 6.1: Current draw of each component in each mode.

The battery supplies 14.7 mA pretty much all day except for a single hot start of the GPS about every day. Now the calculations for battery drain and battery life can be done.

14.7 mA · 24

h
day + 51.8 mA · 1/60
| | h
day = 353.7
| | | mAh
day | (6.3)

1900 mAh
353.7 mAh/day = 5.4 days | (6.4)

The battery will last approximately 5 days, but this is at max use, so in practice the device likely only needs charging once a week.

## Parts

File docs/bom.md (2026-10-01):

# Bill of materials & component rationale

Group 11 — **Smart Bike Theft Tracker** (GPS + LoRaWAN, ultra-low power).

An Altium-style BOM is generated automatically from the schematics:
[`../hardware/Group11_BOM.csv`](../hardware/Group11_BOM.csv)
(`python3 analysis/extract_bom.py`).

## Power / charger sheet — `BatteryCharger.SchDoc`

| Ref | Value | Part / description | Why |
|---|---|---|---|
| U1 | — | **MCP73831T-2ACI/OT** Li-Ion charger (SOT-23-5) | Single-cell 4.2 V charger with status output and programmable current |
| U2 | — | **TPS63001DRCR** buck-boost, 3.3 V | Regulates across the full LiPo range (1.8 V min input) at high efficiency |
| L1 | 2.2 µH | **TDK VLS4012ET-2R2M**, 2.2 A | Buck-boost inductor from the TPS63001 reference design |
| USB1 | — | **USB4125-GF-A-0190** USB Type-C receptacle, 6P | Primary 5 V input, USB-C for EU compliance |
| R1, R2 | 5.1 kΩ | 0603 | USB-C CC1/CC2 pull-downs (sink advertisement) |
| D3 | SMAJ5.0A | TVS diode | Input ESD / overvoltage protection |
| SW2 | — | **500SSP1S1M2QEA** slide switch (SPDT, On-On) | ARMED / DISARMED user control (polled by MCU GPIO) |
| D1 | 598-8110-107F | Red 0805 LED | Charge-status indicator |
| R3 | 140 Ω | 0603 | Status LED series resistor |
| R4, R5 | 1.05 kΩ / 100 Ω | 0603 | Slide-switch / feedback network |
| C1, C2 | 4.7 µF | 0603 MLCC | Charger input/output capacitors (datasheet values) |
| C3, C5, C6 | 10 µF | 0603 MLCC | Buck-boost input/output capacitors |
| C4 | 100 nF | 0603 MLCC | High-frequency decoupling |
| BAT1 | — | **JST `B2B-XH-A`** battery connector | Standard 2-pin LiPo connection |
| — | 1900 mAh | **Jauch LP605060JU** protected LiPo (with PCM) | Fits the board outline; integrated protection circuit module |

## MCU sheet — `MCU.SchDoc`

| Ref | Value | Part / description | Why |
|---|---|---|---|
| U3 | — | **STM32WL5MOCH6TR** (STM32WL5M) | Cortex-M4 + M0+ with **integrated LoRaWAN radio**, matching network and oscillators → no external RF matching or crystals |
| J1 | — | **SMA-J-P-H-ST-EM1** edge-mount SMA | LoRa antenna connector for the `ANT-SS900` antenna |
| SW1 | — | **TL3301AF160QG** tactile switch | User / reset button |
| L2 | 0 Ω | Inductor position, **DNP** | Populated as a 0 Ω link — "not necessary" per design note |
| R6, R7 | 4.7 kΩ | 0603 | I²C / boot pull-ups |
| C7 | 1 µF | X7R 0603 | Bulk decoupling |
| C8, C9 | — | 0603 MLCC | Decoupling |

## GyroSense sheet — `GyroSense.SchDoc`

| Ref | Value | Part / description | Why |
|---|---|---|---|
| U6 | — | **ADXL345BCCZ-RL7** | 3-axis accelerometer with **motion interrupt** that wakes the MCU from deep sleep; 3 × 5 mm, FIFO, tap/activity/inactivity/free-fall |
| R11 | 4.7 kΩ | 0603 | I²C pull-up |
| C_A1 | 0.1 µF | 0603 MLCC | Decoupling |
| C_A2 | 10 µF | 0603 MLCC | Bulk decoupling |

## GPS sheet — `GPS.SchDoc`

| Ref | Value | Part / description | Why |
|---|---|---|---|
| U5 | — | **NEO-6M-0-001** GPS module | UART NMEA output, compact (16 × 12.2 × 2.4 mm), 2.7–3.6 V |
| J2 | — | **A-1JB** U.FL / AMC connector | GPS antenna feed (50 Ω) |
| BAT2 | — | Coin-cell retainer (`2998`) | Backup cell keeps RTC/ephemeris for a **hot start** |
| D2 | STPS0540Z | Schottky rectifier | Backup-battery ORing / reverse protection |
| Q5 | CSD13381F4 | N-channel MOSFET (3-PicoStar) | **Power gating** of the GPS rail to save energy |
| D4 | LTST-C171KGKT | Green LED | GPS fix / status indication |
| L3 | 27 nH | LQG18HN27NJ00D chip inductor | RF bias/choke for the antenna path |
| R8, R9, R10 | 1 kΩ / 3.3 kΩ / 22 Ω | 0603 | LED, UART and RF series resistors |
| C10 | 1 µF | 0603 MLCC | Decoupling |

## Notes

- **U3** is a multi-part schematic symbol (three units: MCU core, radio and
  power/RF); it is one physical component, so the generated CSV collapses the
  units to a single line.
- The block diagram also shows a `24AA32A` EEPROM inside the GPS block as a
  possible configuration store; it is **not** populated in the schematic, so it
  is omitted from the BOM.
- All RF parts and the RF feeds were chosen together: 50 Ω controlled-impedance
  coplanar waveguide with ground on a 4-layer stack (see
  [`../docs/system-design.md`](../docs/system-design.md)).

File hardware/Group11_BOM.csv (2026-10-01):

Sheet | Reference | Value | Library Reference | Footprint | Description
BatteryCharger | BAT1 | B2B-XH-A | B2B-XH-A
BatteryCharger | C1 | 4u7 | CAP_0603 |  | Capacitor SMD 0603
BatteryCharger | C2 | 4u7 | CAP_0603 |  | Capacitor SMD 0603
BatteryCharger | C3 | 10u | CAP_0603 |  | Capacitor SMD 0603
BatteryCharger | C4 | 100n | CAP_0603 |  | Capacitor SMD 0603
BatteryCharger | C5 | 10u | CAP_0603 |  | Capacitor SMD 0603
BatteryCharger | C6 | 10u | CAP_0603 |  | Capacitor SMD 0603
BatteryCharger | D1 | 598-8110-107F | RED_LED_0805 |  | 598-8110-107F 598-8110-107F, Dialight, SMD LED 0805 Package, Red Single color SOLD IN INCREMENTS OF 4000. (REEL)
BatteryCharger | D3 | SMAJ5.0A | SMAJ5.0A |  | ESD Protection Diode
BatteryCharger | L1 | VLS4012ET-2R2M | VLS4012ET-2R2M |  | INDUCTOR, 2.2UH, 2.2A, 20%, SMD; Product Range:TDK - VLS-E Series; Inductance:2.2ÂµH; Inductance Tolerance:Â± 20%; Inductor Construction:Shielded; DC Resistance Max:0.081ohm; RMS Current (Irms):2.2A; Saturation Current (Isat):1.9A; Case Dimensions:4mm x 4mm x 1.2mm; SVHC:No SVHC (20-Jun-2013)
BatteryCharger | R1 | 5k1 | RES_0603 |  | Resistor SMD 0603
BatteryCharger | R2 | 5k1 | RES_0603 |  | Resistor SMD 0603
BatteryCharger | R3 | 140R | RES_0603 |  | Resistor SMD 0603
BatteryCharger | R4 | 1k05 | RES_0603 |  | Resistor SMD 0603
BatteryCharger | R5 | 100R | RES_0603 |  | Resistor SMD 0603
BatteryCharger | SW2 | 500SSP1S1M2QEA | 500SSP1S1M2QEA |  | SLIDE, 5A, 120VAC/28VDC SPDT, On-On Through Hole
BatteryCharger | U1 | MCP73831T-2ACI/OT | MCP73831T-2ACI/OT |  | Li-Ion Charge Controller 4.2V SOT23-5
BatteryCharger | U2 | TPS63001DRCR | TI-TPS63001DRC10-3000X1650TP |  | Buck-Boost Voltage Converter with 1.8 to 5.5 V Input and 3.3 V Output, -40 to 85 degC, 10-Pin SON (DRC), Green (RoHS & no Sb/Br)
BatteryCharger | USB1 | USB4125-GF-A-0190 | USB type-C |  | CONN RCPT TYPE C 6P SMD RA
GPS | BAT2 | 2998 | 2998 |  | BATTERY RETAINER COIN 6.8MM SMD
GPS | C10 | 1u | CAP_0603 |  | Ceramic Capacitor SMD 0603
GPS | D2 | STPS0540Z | DSKY-AK-2 |  | Schottky Rectifier, 0.5 A, 40 V, 2-Pin SOP (SOD-123), RoHS, Tape and Reel
GPS | D4 | LTST-C171KGKT | 8706943c75ba83719d021d2fdc84c58 |  | LED GREEN CLEAR SMD
GPS | J2 | A-1JB | A-1JB |  | U.FL (UMCC), AMC Connector Jack, Male Pin 50 Ohms Surface Mount Solder
GPS | L3 | LQG18HN27NJ00D | LQG18HN27NJ00D |  | Ind RF Chip Multi-Layer 27nH 5% 100MHz 12Q-Factor Air 300mA 0603 Paper T/R
GPS | Q5 | CSD13381F4 | 9fa42dd10ff43da9cbcc9b3293ff909 |  | MOSFET N-CH 12V 2.1A 3PICOSTAR
GPS | R10 | 22R | RES_0603 |  | Resistor SMD 0603
GPS | R8 | 1k | RES_0603 |  | Resistor SMD 0603
GPS | R9 | 3k3 | RES_0603 |  | Resistor SMD 0603
GPS | U5 | NEO-6M-0-001 | NEO-6M-0-001 |  | GPS Module
GyroSense | C_A1 | 0.1 uF | CAP_0603 |  | Capacitor SMD 0603
GyroSense | C_A2 | 10 uF | CAP_0603 |  | Capacitor SMD 0603
GyroSense | R11 | 4.7K | RES_0603 |  | Resistor SMD 0603
GyroSense | U6 | ADXL345BCCZ-RL7 | ADXL345BCCZ-RL7 |  | ADXL345BCCZ-RL7 Analog Devices, 3-Axis Accelerometer, I2C, SPI, 14-Pin LGA 0.3 V to +3.9 V 40C to +105C
MCU | C7 | AC0805KKX7R5BB105 | 11868f565c42a9108669ba33697ecf6 |  | AC0805 1 uF X7R 10.00% 6.3 V
MCU | C8 | Capacitor | CAP_0603 |  | Capacitor SMD 0603
MCU | C9 | Capacitor | CAP_0603 |  | Capacitor SMD 0603
MCU | J1 | SMA-J-P-H-ST-EM1 | LoRa antenna connector |  | CONN SMA JACK STR 50OHM EDGE MNT
MCU | L2 | 0R | Inductor |  | Not necessary. Place 0 ohm resistor
MCU | R6 | 4k7 | RES_0603 |  | Resistor SMD 0603
MCU | R7 | 4k7 | RES_0603 |  | Resistor SMD 0603
MCU | SW1 | TL3301AF160QG | 94cebf9f54af8bed749b87481745719 |  | SWITCH TACTILE SPST-NO 0.05A 12V
MCU | U3 | STM32WL5MOCH6TR | STM32WL5MOCH6TR |  | Multiprotocol LPWAN dual-core module 32-bit Arm Cortex-M4/M0+ LoRa,(G)FSK, (G)MSK, BPSK

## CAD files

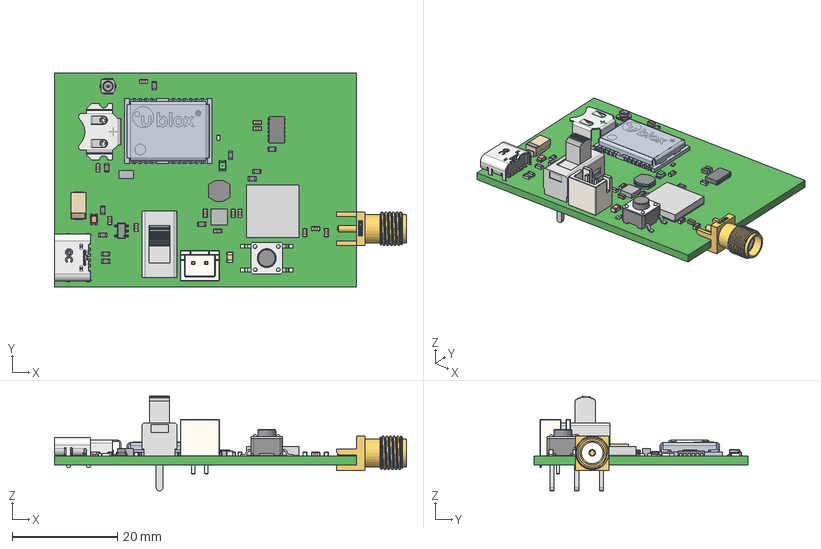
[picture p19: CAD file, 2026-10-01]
hardware/Smart_Bike_Theft_Tracker.step
66.8 x 40.6 x 18.0 mm
Texas Logo Yury - Copy
Texas Logo Yury
CAP-0603 x 13
500SSP1S1M2QEA
A-1JB_RGB8421504
NEO-6M-0-001
STM32WL5MOCH6TR
SMA-J-P-H-ST-EM1
insulator
logo
PinsArrayL
PinsArrayR
Dialight Logo adjustable
B2B-XH-A
JST Logo adjustable
GCT
Extruded x 2
TL1105CONTACTDOME
TL3301GBODY
TL1105COVER
TL1105-3301ACTUATOR A 5
E-Switch Logo
pcb
top
lead
emitter
lead_MIR
marking
name

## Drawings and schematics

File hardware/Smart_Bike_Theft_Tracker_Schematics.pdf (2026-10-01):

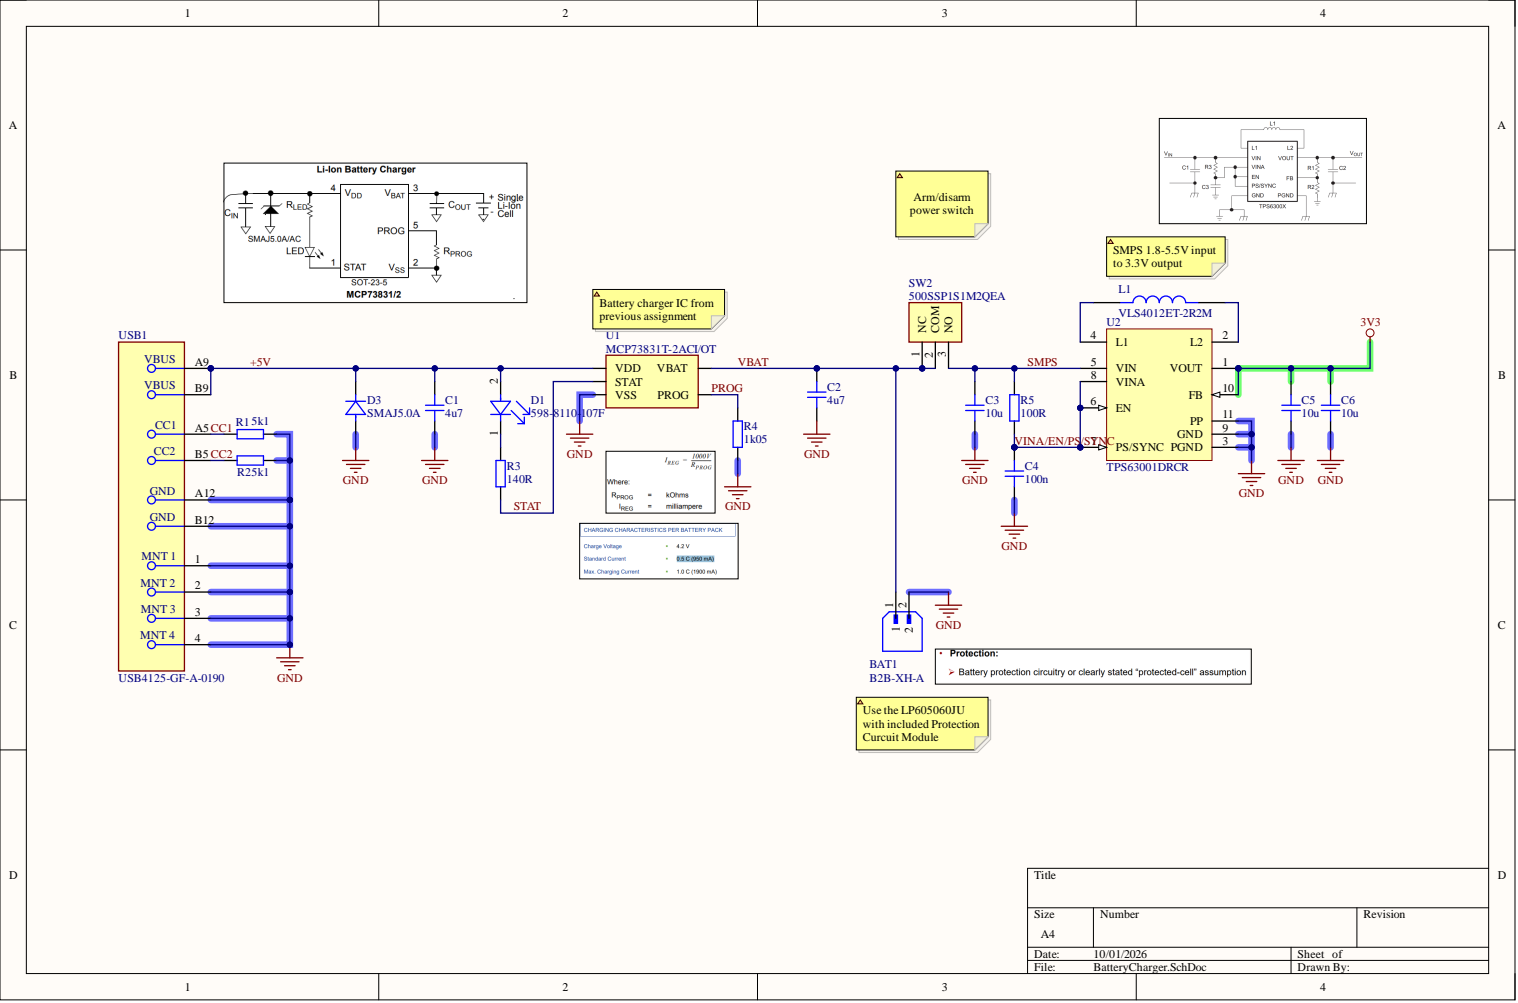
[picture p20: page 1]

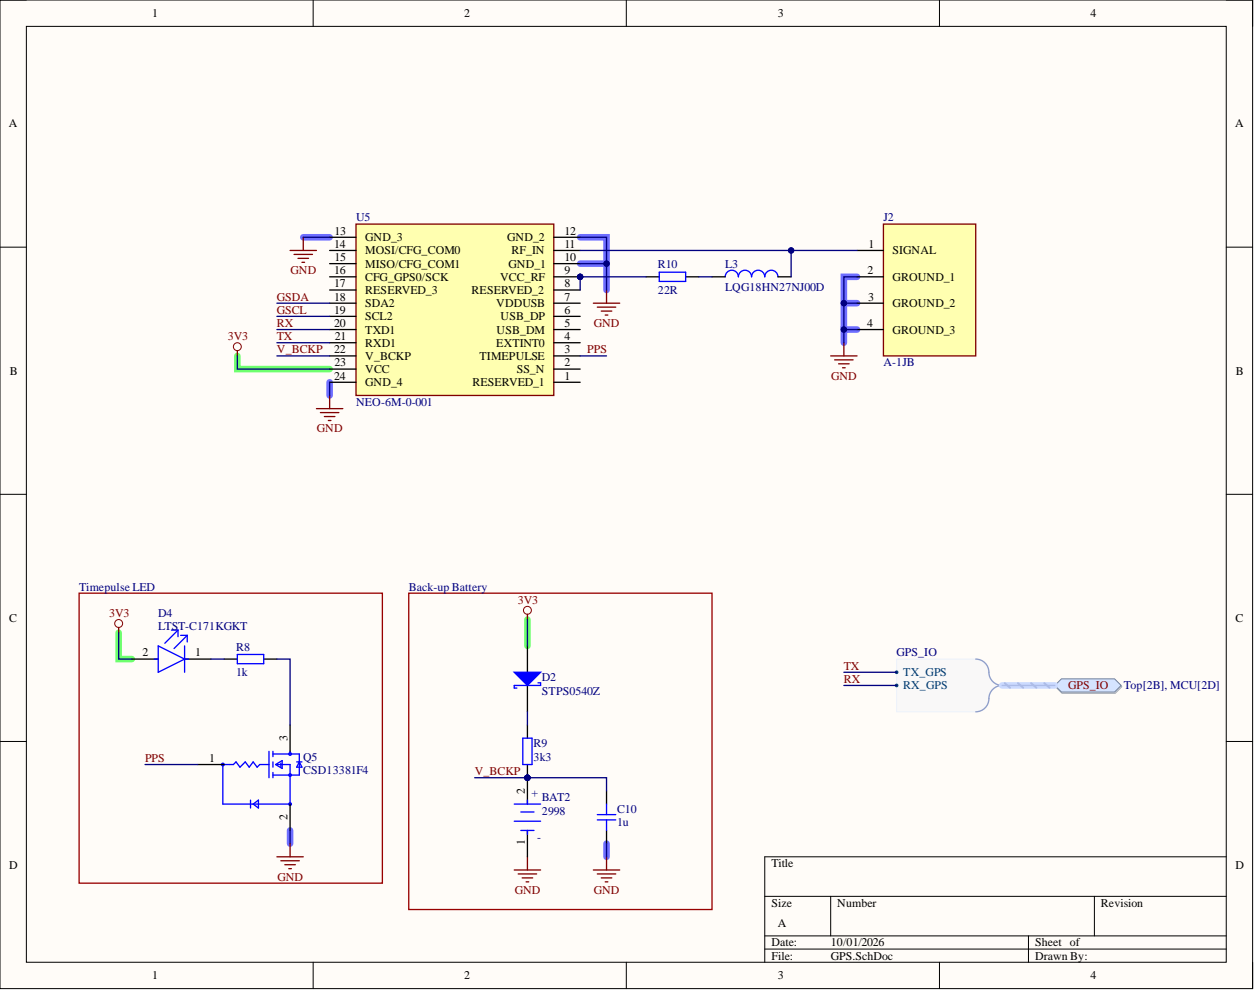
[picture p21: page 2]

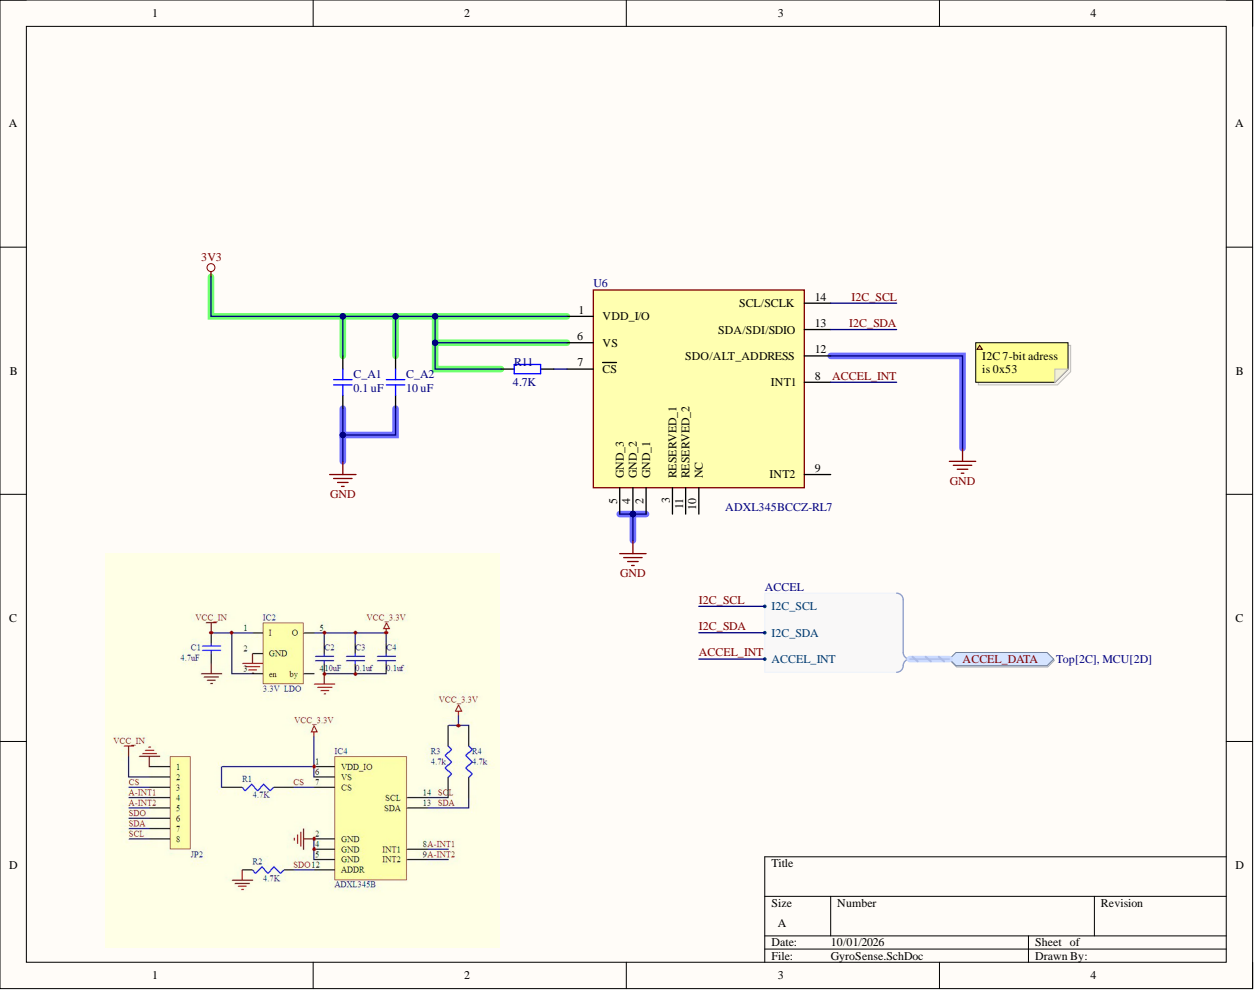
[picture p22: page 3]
File:; GyroSense.SchDoc; Drawn By:; ACCEL_DATA; Top[2C], MCU[2D]; VDD_I/O 1; GND_1 2; RESERVED_1 3; GND_2 4 GND_3 5; INT2; 9 NC 10 RESERVED_2 11 SDO/ALT_ADDRESS; I2C 7-bit adress is 0x53

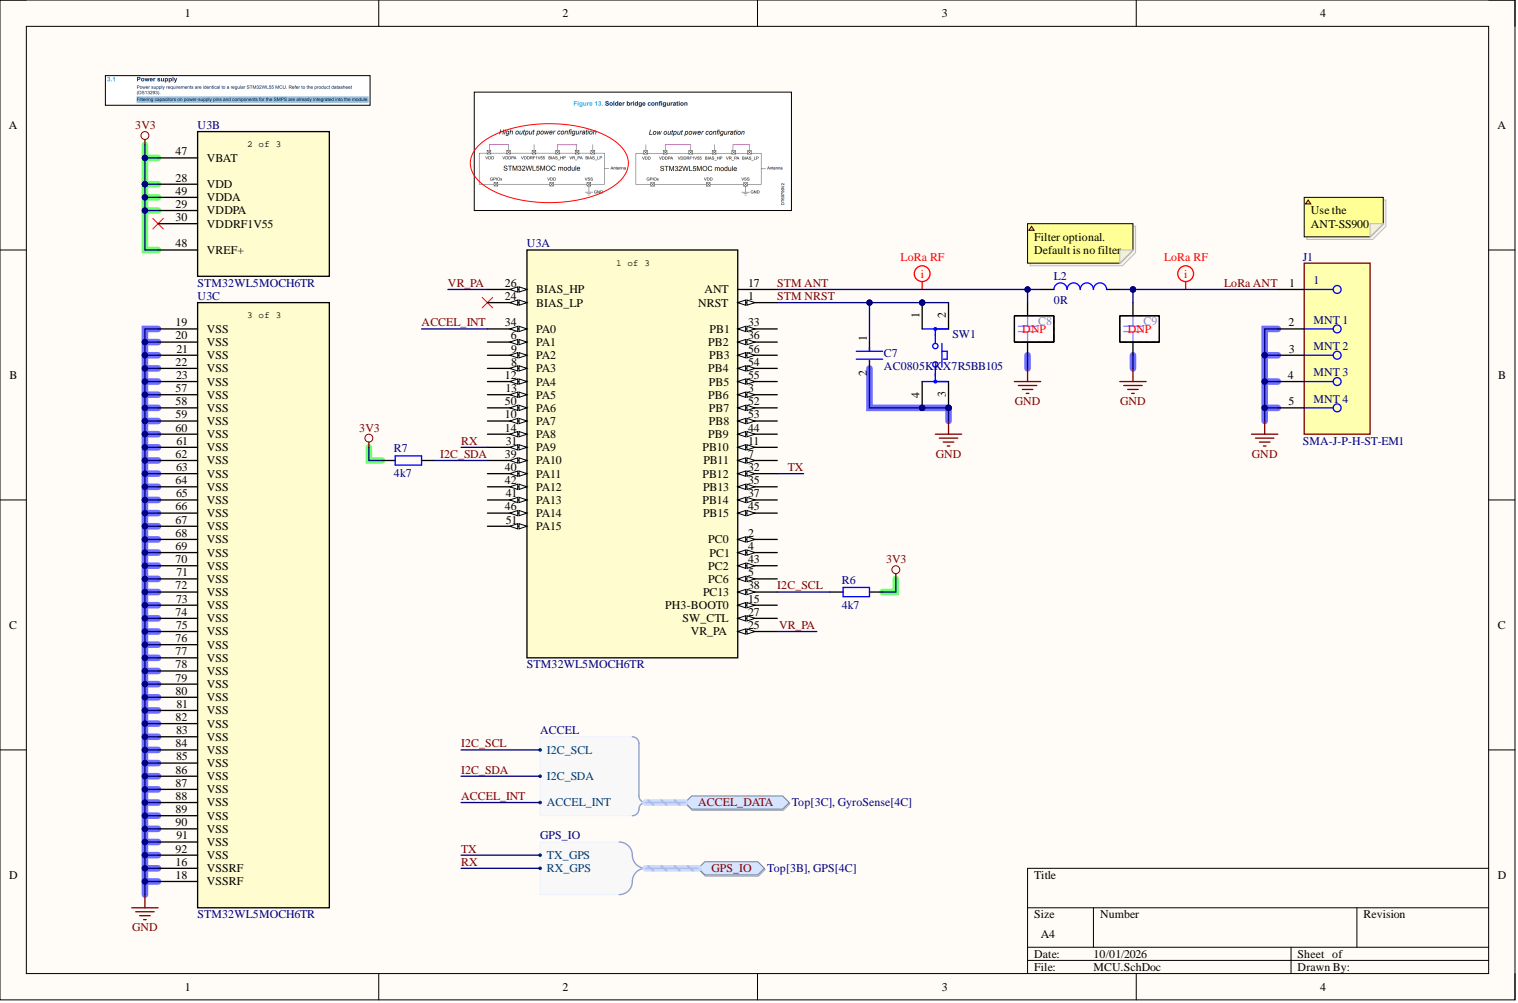
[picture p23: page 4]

VDDA 49

VDDRF1V55 30

Filter optional.
Default is no filter.

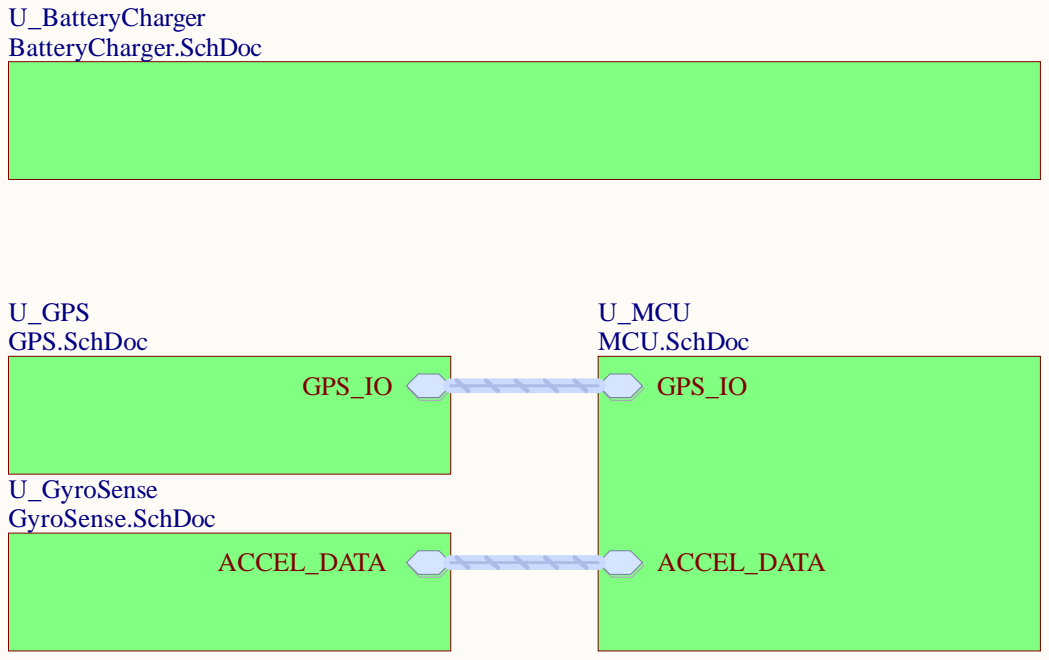
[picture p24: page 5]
File:; Top.SchDoc; Drawn By:

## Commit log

2026-10-01 Add Smart Bike Theft Tracker final project (DTU 34374, Group 11)
    Ultra-low-power GPS + LoRaWAN bike theft tracker, co-designed with
    Louis Sønderby Pelletier:
    - hierarchical Altium schematic (power, MCU, accelerometer, GPS) and
    4-layer PCB with 50 ohm controlled-impedance RF feeds
    - STM32WL5MOCH6TR (integrated LoRaWAN), ADXL345 motion wake, NEO-6M GPS
    - USB-C -> MCP73831 charger -> 1900 mAh LiPo -> TPS63001 buck-boost 3.3 V
    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
    [BatteryCharger.SchDoc, GPS.SchDoc, Group11_BOM.csv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]
2026-10-01 Add schematics, PCB layout and a rendered 3D model
    - export all five schematic sheets (top hierarchy, power, MCU, GyroSense,
    GPS) as high-res PNGs from the Altium Smart PDF
    - add the 4-layer PCB top-copper layout export
    - tessellate the Altium STEP model with gmsh and render a shaded isometric
    3D image (tools/render_step_3d.py), so no 3D screenshot is needed
    - wire the images into the README as a schematic/PCB gallery
    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
    [Smart_Bike_Theft_Tracker.step]
2026-10-01 Use the Altium 3D render and tidy the README
    - replace the tessellated 3D image with the Altium isometric export
    - reword the 3D/PCB sections so the README reads as project documentation
    - drop the now-unused STEP renderer and preview helper scripts
